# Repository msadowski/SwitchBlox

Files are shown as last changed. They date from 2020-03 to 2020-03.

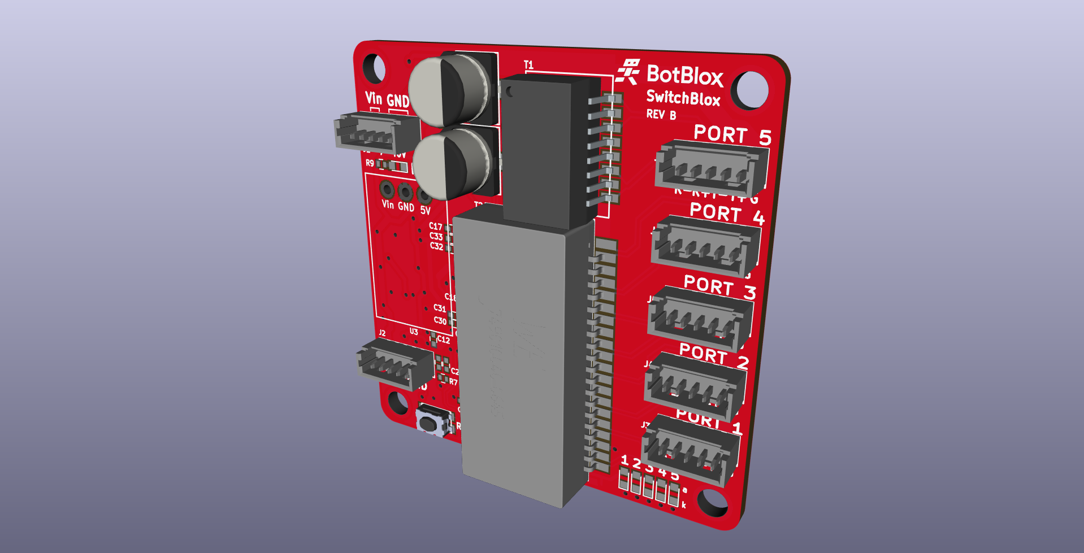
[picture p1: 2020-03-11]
Hardware/Reference Images/Iso.png

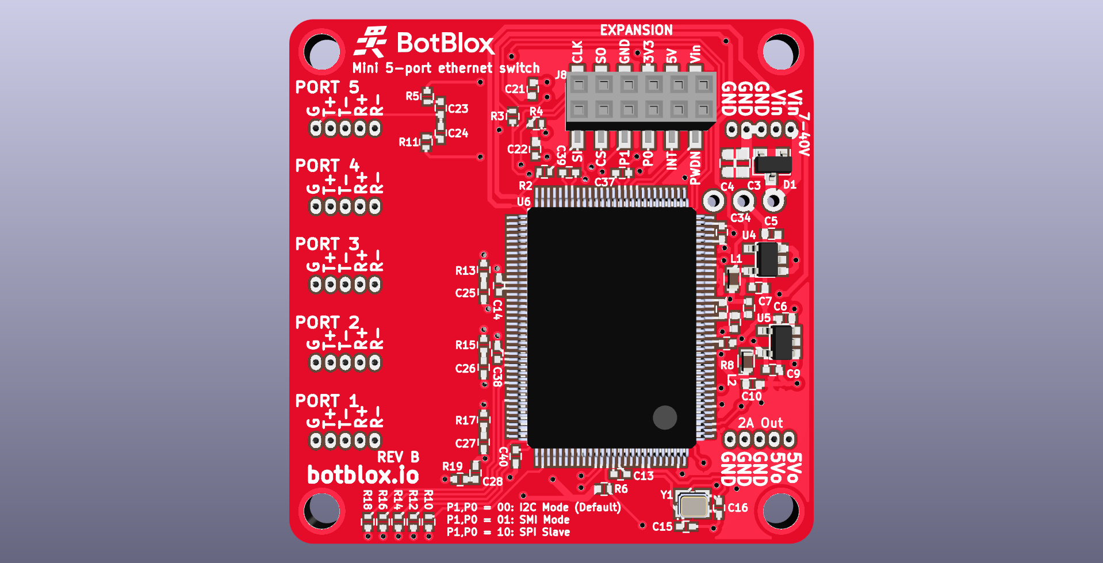
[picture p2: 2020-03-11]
Hardware/Reference Images/Bottom.png

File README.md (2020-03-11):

# SwitchBlox
Compact and robust 10/100MB 5 Port Ethernet Switch

Small Ethernet Switch for demanding applications.
Wide, protected input voltage range from 7 to 40V.
5V, 2A output available.
5 port ethernet network switch works out the box.
10/100MB Speed.
Auto MDI-X crossover.
All cables included, with extension cable set available.
SPI interface for advanced Rapid Spanning Tree (RSTP) applications.

In this repo you will find

- Hardware files (in Kicad)
- Firmware files (C++ mainly) (Haven't started this yet)
- Software files (Python) (Haven't started this yet, ideally I'd like a nice GUI to talk to the firmware to configure SwitchBlox)

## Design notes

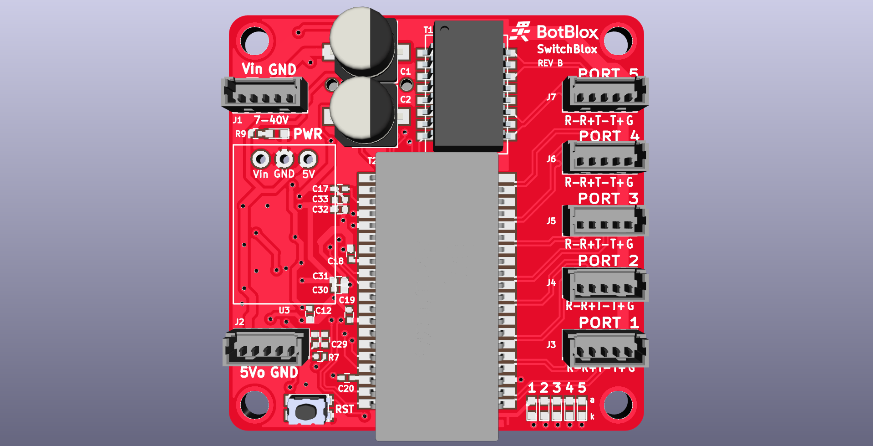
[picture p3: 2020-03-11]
Hardware/Reference Images/Front.png

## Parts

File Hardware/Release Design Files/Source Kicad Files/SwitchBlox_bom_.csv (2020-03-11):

Component | Description | Part | References | Value | Footprint | Quantity Per PCB | Datasheet | Voltage Rating | MPN | Tolerance | Field8 | Field4 | Field6 | Field5
1 | Unpolarized capacitor | C_Small | C3 C4 | 0.1u | C_0603 | 2 | ~ | 50V | CL10B104MB8NNNC
2 | Unpolarized capacitor | C_Small | C23 C24 C25 C26 C27 C28 | 1000p | C_0402 | 6 | ~ | 50V | GCM155R71H102KA37D
3 | Unpolarized capacitor | C_Small | C5 C6 C7 C8 C9 C10 C11 C12 C13 C14 C17 C18 C19 C20 C21 C22 C29 C30 C31 C32 C33 C34 C35 C36 C37 C38 C39 C40 | 1u | C_0402 | 28 | ~ | 10V | CL05A105MP5NNNC
4 | Unpolarized capacitor | C_Small | C15 C16 | 22p | C_0402 | 2 | ~ | 50V | CBR04C220F5GAC
5 | Polarised capacitor | CP1_Small | C1 C2 | 22u | Radial, Can - SMD | 2 | ~ | 50V | 865080643008
6 | Dual diode, common cathode | D_x2_KCom_AAK | D1 | 36Vb | SOT-23 | 1 | ~ |  | DESD34VS2SO-7
7 | LED generic | LED | D2 D3 D5 D7 D9 D11 | Green | LED_0603 | 6 | ~ |  | 150060GS75000
8 | Generic connector, single row, 01x06, script generated (kicad-library-utils/schlib/autogen/connector/) | Conn_01x06_Male | J8 | 2x3 | 2x3_2mm | 1 | ~
9 |  | CONN_HEADER_V_2 | J1 J2 | CONN_HEADER_V_2 | WM1731-ND | 2 |  |  | 0530470210
10 |  | CONN_HEADER_V_5 | J3 J4 J5 J6 J7 | CONN_HEADER_V_5 | WM1734-ND | 5 |  |  | 0530470510
11 | Ferrite bead, small symbol | Ferrite_Bead_Small | L1 L2 | Ferrite | R_0603 | 2 | ~ |  | MPZ1608S101ATAH0
12 | Net Tie, 2 pins | Net-Tie_2 | NT1 | Net-Tie_2 | NETTIE | 1 | ~ |  | DNI
13 | Resistor, small symbol | R_Small | R1 R2 R3 R4 R6 R7 | 10k | R_0402 | 6 | ~ |  | RR0510P-103-D
14 | Resistor, small symbol | R_Small | R8 | 12.4k | R_0402 | 1 | ~ |  | RR0510P-1242-D | 0.5%
15 | Resistor, small symbol | R_Small | R9 R10 R12 R14 R16 R18 | 220R | R_0402 | 6 | ~ |  | RR0510P-221-D
16 | Resistor, small symbol | R_Small | R5 R11 R13 R15 R17 R19 | 75R | R_0402 | 6 | ~ |  | ERJ-2RKF75R0X
17 | Push button switch, generic, two pins | SW_Push | SW1 | SW_Push | Tact, SMT | 1 |  |  | KMR621NG LFS
18 |  | H1102FNL | T1 | H1102FNL | H1102FNL | 1 |  |  | H1102FNL
19 |  | H1164NL | T2 | H1164NL | H1164NL | 1 |  |  | H1164NL
20 |  | DC-DC | U3 | DC-DC | OKI-78SR-5_1.5-W36HC | 1 |  |  | OKI-78SR-5/1.5-W36H-C
21 |  | KSZ8895MQXCA | U6 | KSZ8895MQXCA | PQFP-128 | 1 | 576-4855-ND |  | KSZ8895MQXCA |  | KSZ8895 Series 3.3 V 129 mA Integrated 5-Port 10/100 Managed Ethernet Switch | https://www.digikey.com/product-detail/en/microchip-technology/KSZ8895MQXCA/576-4855-ND/4901386 | Microchip | BFQFP-128 Microchip
22 |  | SOT-23-5 | U4 U5 | SOT-23-5 | SOT23-5 | 2 |  |  | MIC5504-3.3YM5-TR MIC5504- 1.2YM5-TR
23 | Two pin crystal | Crystal | Y1 | 25MHz | 2-SMD, No Lead | 1 | ~ |  | ECS-250-20-3X-TR
Component Groups: | 23
Component Count: | 85
Fitted Components: | 85
Number of PCBs: | 1
Total components: | 85
Schematic Version:
Schematic Date:
BoM Date: | 11/3/2018 00:00:17
Schematic Source: | D:\DawnSpark\_Upwork\SwitchBlox-master\Release Design Files\SwitchBlox.sch
KiCad Version: | Eeschema (5.0.0)

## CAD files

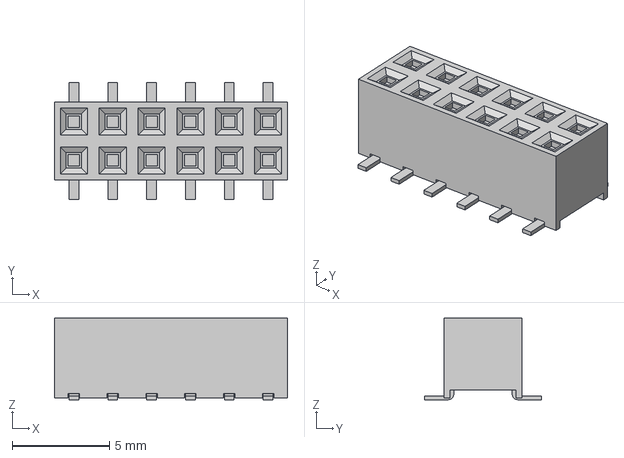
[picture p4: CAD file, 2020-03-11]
Hardware/Library Files/3D Models/A3-12DA-2SV.stp
12.0 x 6.00 x 4.20 mm

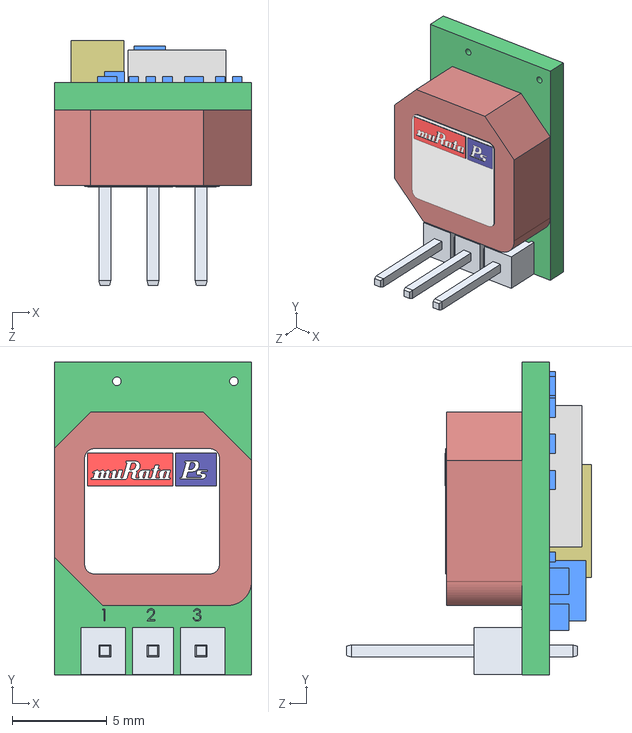
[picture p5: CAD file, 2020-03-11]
Hardware/Release Design Files/Source Kicad Files/3D/mps_dcdc_oki_78sr_horiz_a.step
10.4 x 16.5 x 12.9 mm

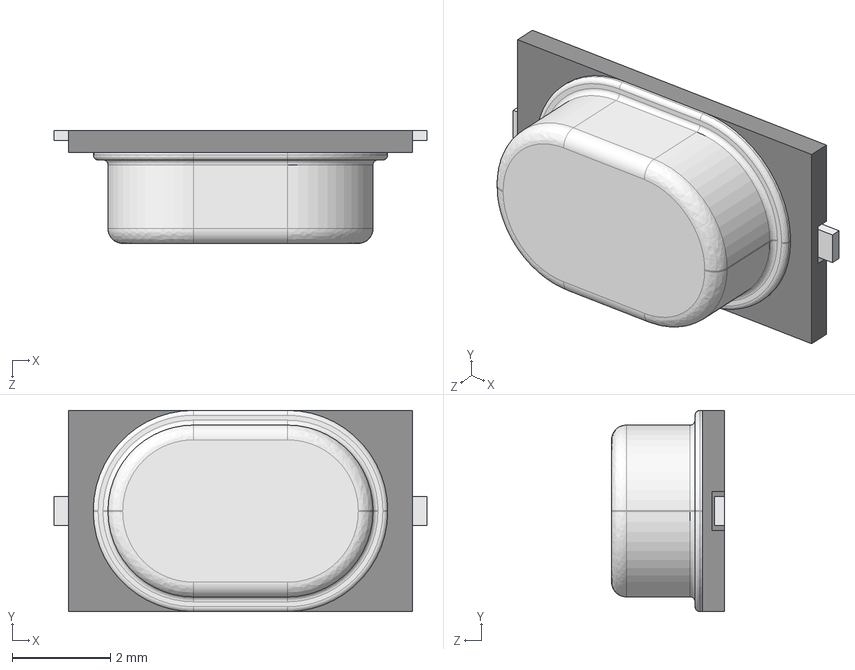
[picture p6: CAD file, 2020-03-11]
Hardware/Release Design Files/Source Kicad Files/3D/User Library-CSM-3X/User Library-CSM-3X.STEP
7.60 x 4.10 x 2.30 mm
User Library-CSM-3X_Fusion001
User Library-CSM-3X_Cut
User Library-CSM-3X_Fillet004

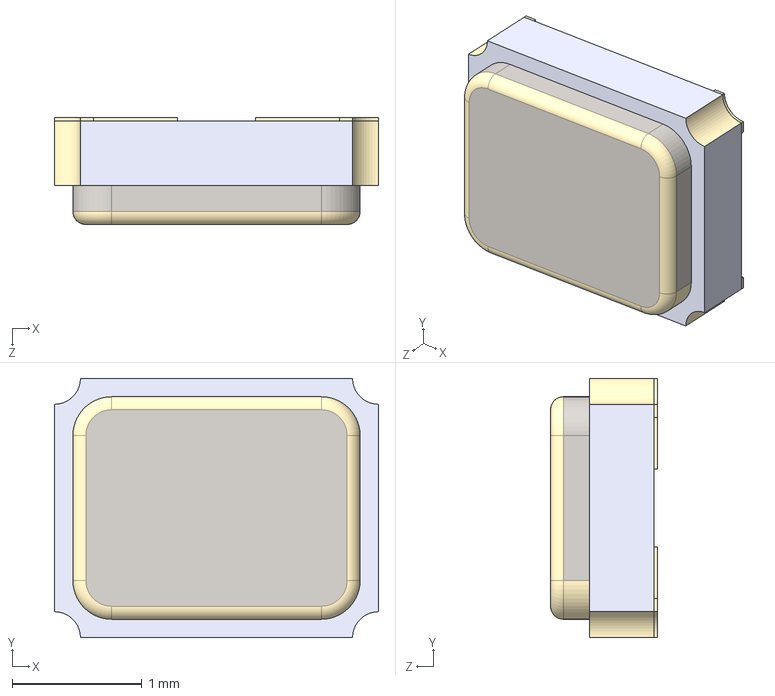
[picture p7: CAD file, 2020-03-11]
Hardware/Release Design Files/Source Kicad Files/3D/User Library-SM2520-4/User Library-SM2520-4.STEP
2.50 x 2.00 x 0.825 mm

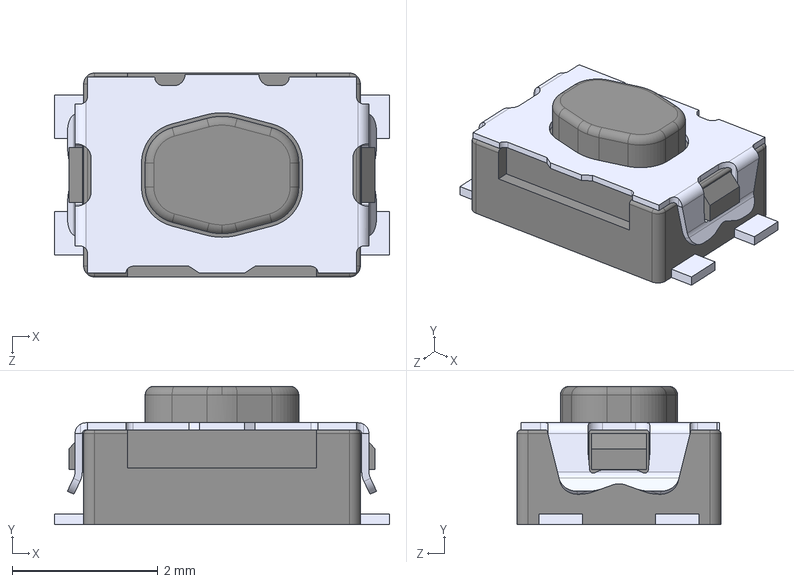
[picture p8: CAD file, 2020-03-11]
Hardware/Release Design Files/Source Kicad Files/3D/KMR621NG LFS--3DModel-STEP-56544.STEP
4.60 x 1.90 x 2.80 mm

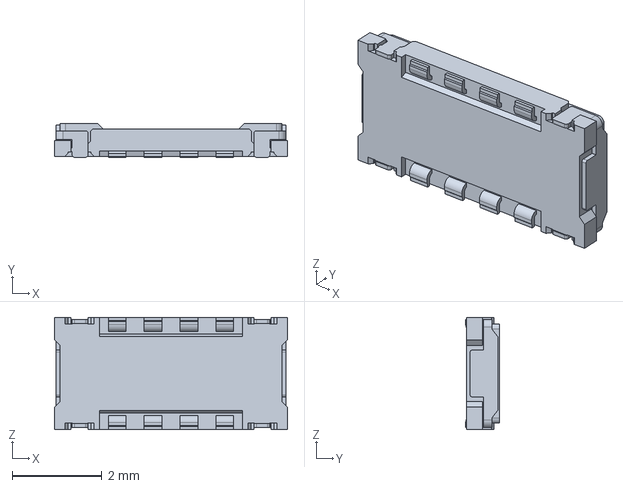
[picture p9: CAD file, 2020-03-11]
Hardware/Release Design Files/Source Kicad Files/3D/104249-0810_stp/1042490810.stp
5.20 x 0.75 x 2.50 mm

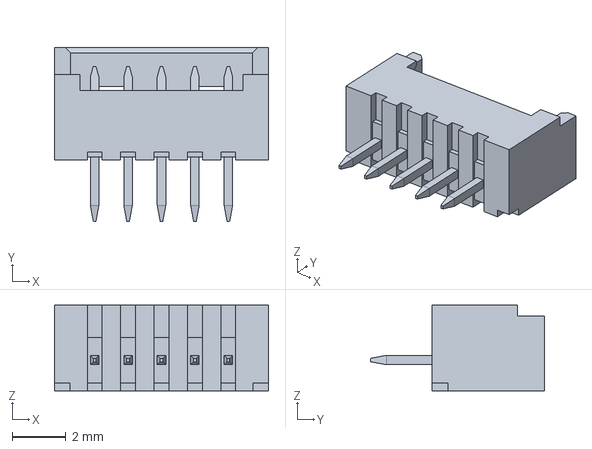
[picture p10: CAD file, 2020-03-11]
Hardware/Release Design Files/Source Kicad Files/3D/53047-0510_stp/530470510.stp
8.00 x 6.50 x 3.20 mm

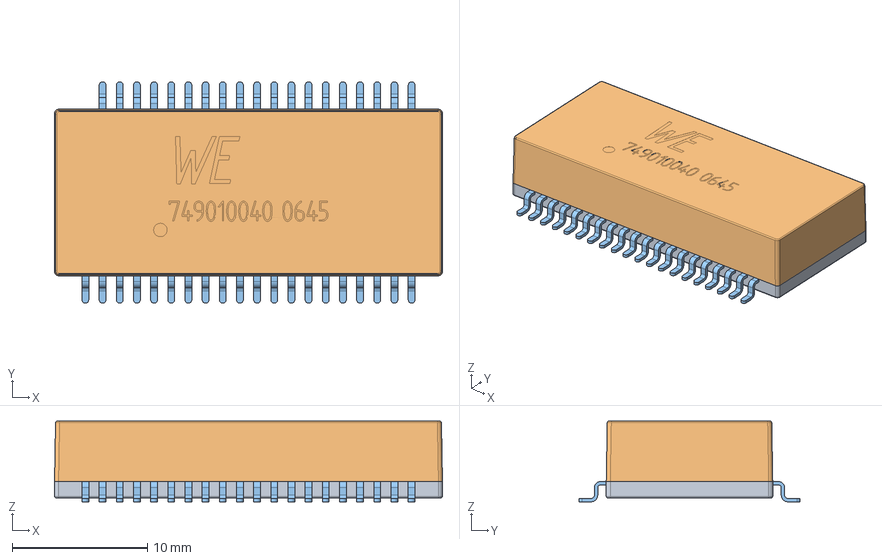
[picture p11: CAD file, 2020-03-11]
Hardware/Release Design Files/Source Kicad Files/3D/88347741-3-45803/45803.stp
28.7 x 16.4 x 5.97 mm

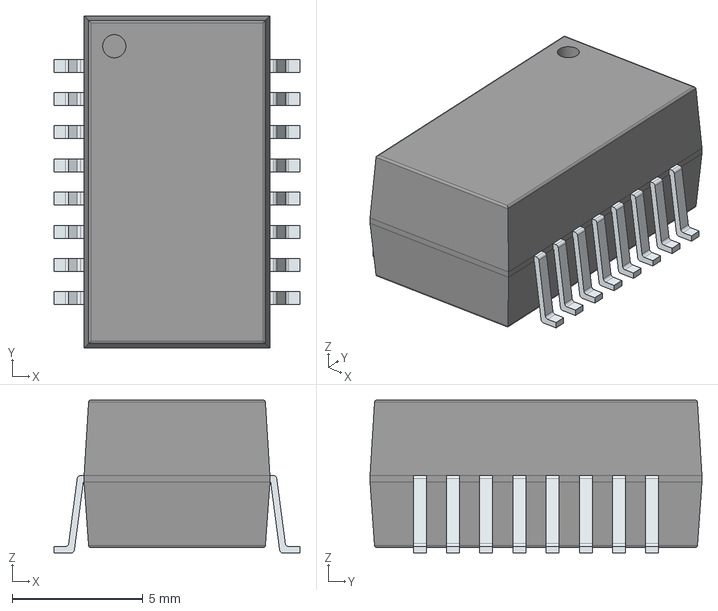
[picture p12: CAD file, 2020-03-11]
Hardware/Release Design Files/Source Kicad Files/3D/LIB_B78476A8065A003/B78476A8065A003/3D/B78476A8065A003.stp
9.40 x 12.7 x 5.85 mm
PinsArrayLR

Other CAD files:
Hardware/Library Files/3D Models/mps_dcdc_oki_78sr_horiz_a.step
Hardware/Release Design Files/Source Kicad Files/3D/LIB_B78476A8065A003/B78476A8065A003/3D/B78476A8065A003.stl
Hardware/Release Design Files/Source Kicad Files/3D/LIB_B78476A8065A003/B78476A8065A003/Allegro/soic127p940x585-16n.psm
Hardware/Release Design Files/Source Kicad Files/3D/LIB_B78476A8065A003/B78476A8065A003/DEHDL/B78476A8065A003/chips/chips.prt

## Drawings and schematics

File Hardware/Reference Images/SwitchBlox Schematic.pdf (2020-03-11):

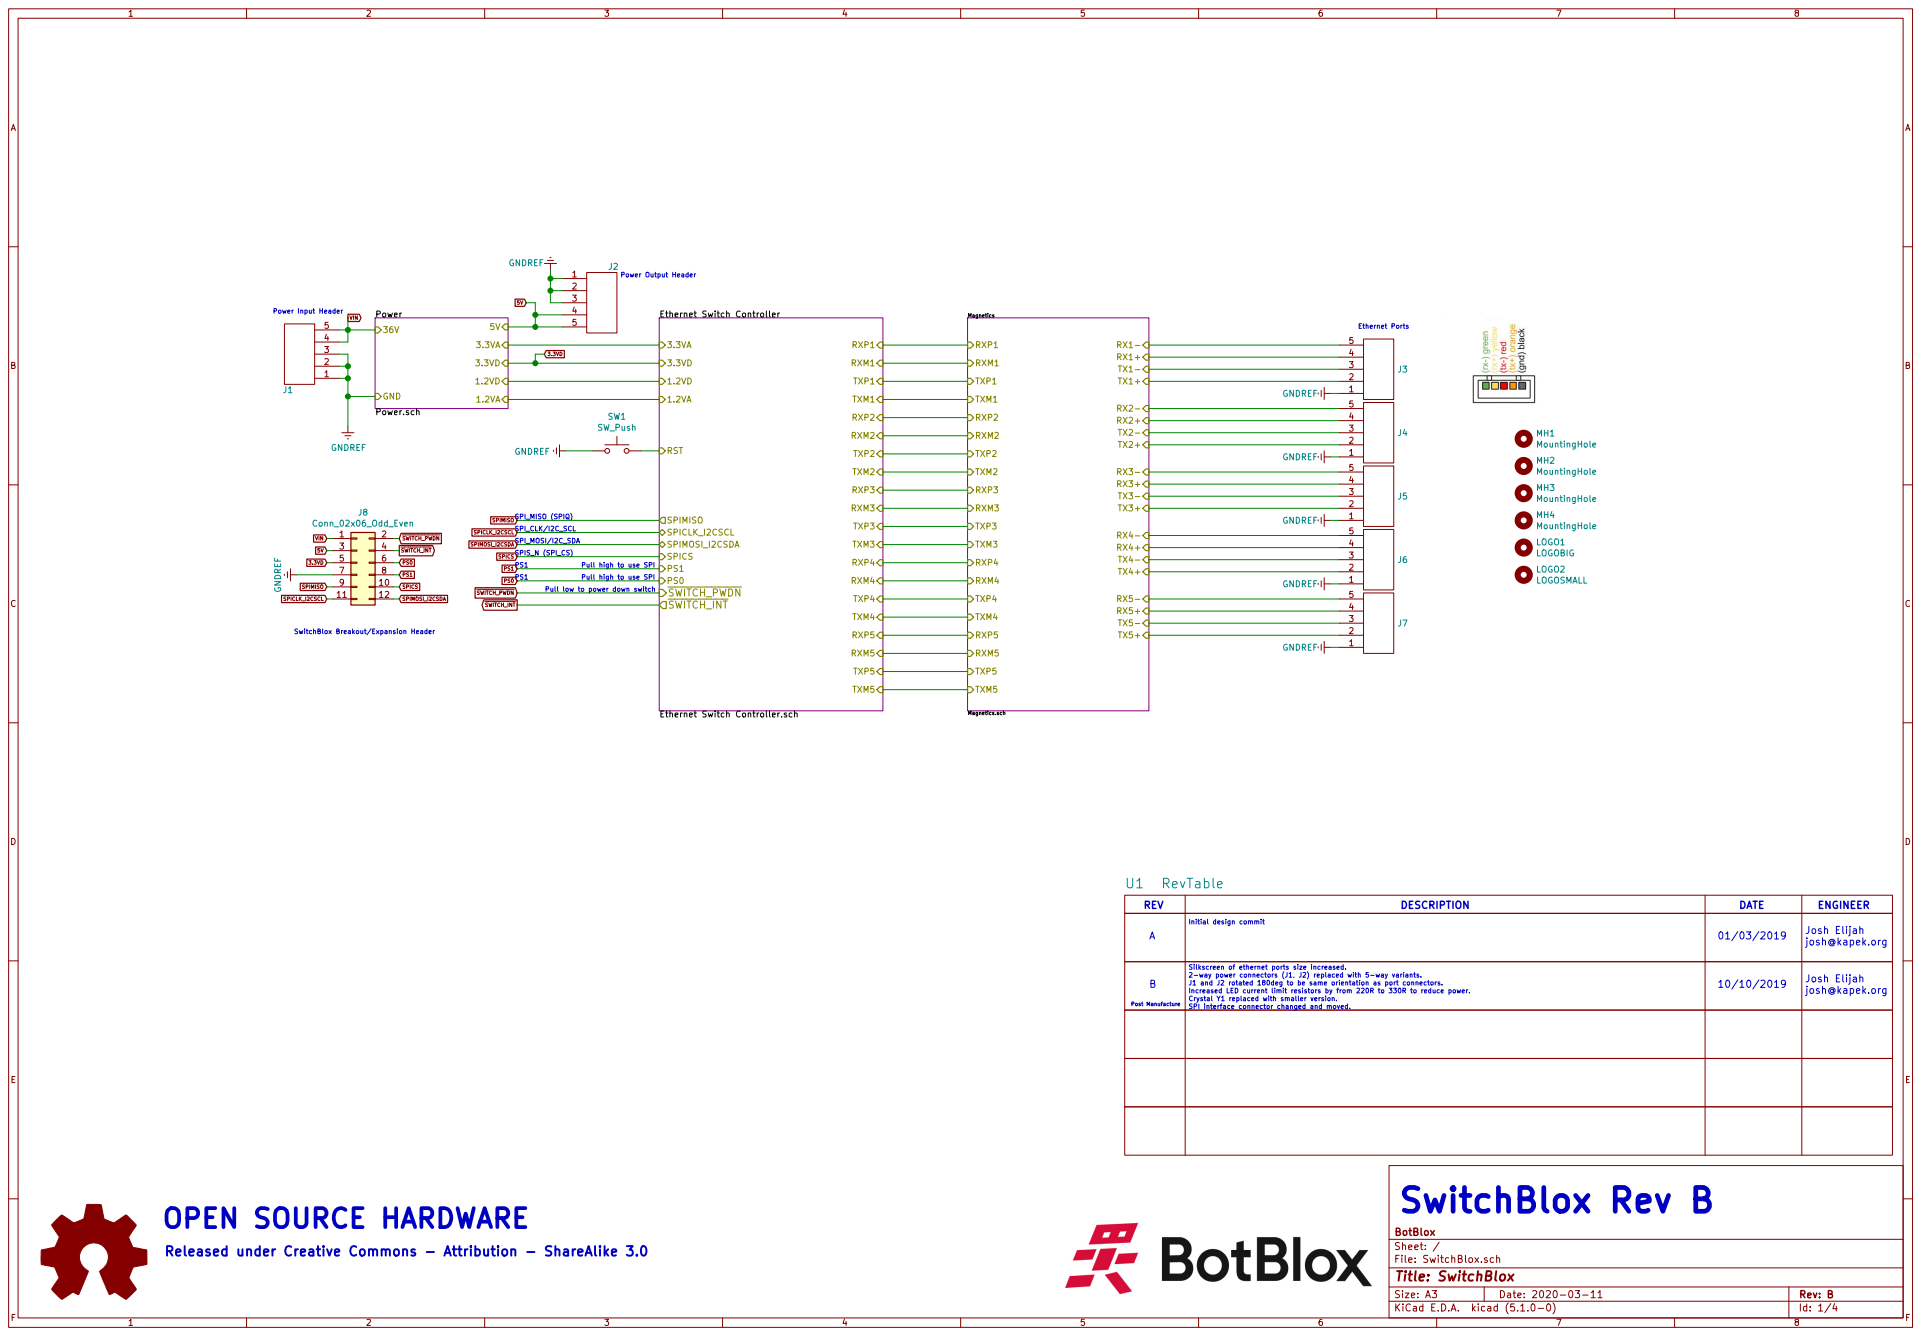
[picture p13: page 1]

SWITCH_INT VIN SwitchBlox Breakout/Expansion Header VIN1

Ethernet Switch Controller Ethernet Switch Controller.sch

A | | 01/03/2019 B | josh@kapek.org

Post Manufacture | Silkscreen of ethernet ports size increased. 2-way power connectors (J1, J2) replaced with 5-way variants. J1 and J2 rotated 180deg to be same orientation as port connectors. Increased LED current limit resistors by from 220R to 330R to reduce power. Crystal Y1 replaced with smaller version. SPI interface connector changed and moved. | | josh@kapek.org

10/10/2019 SwitchBlox Rev B OPEN SOURCE HARDWARE

File: SwitchBlox.sch Sheet: / BotBlox

Released under Creative Commons - Attribution - ShareAlike 3.0

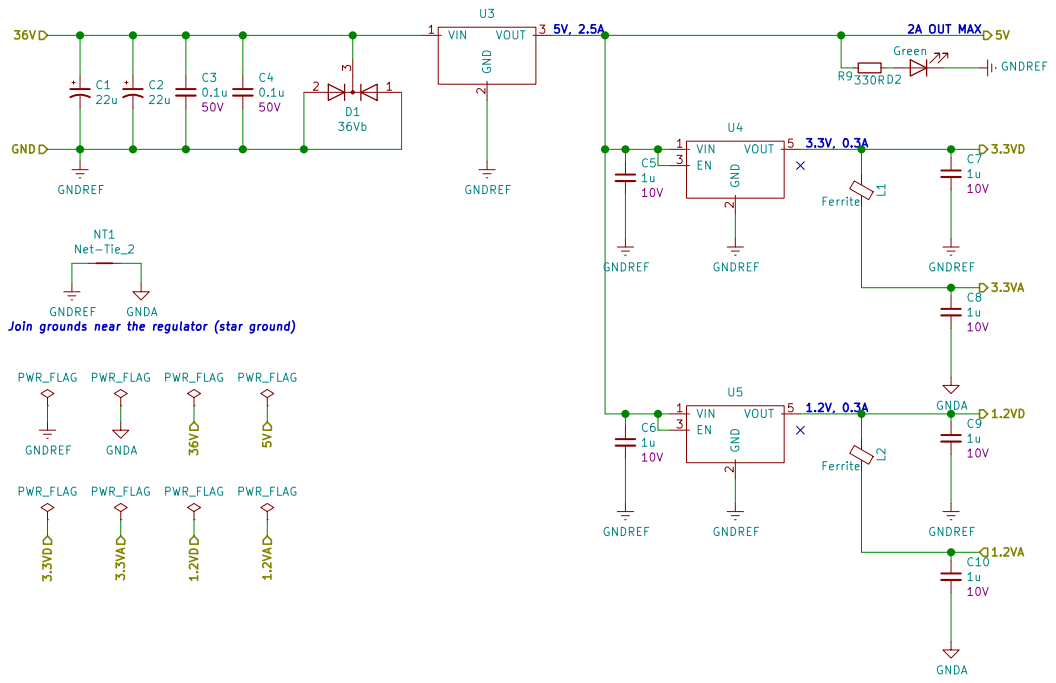
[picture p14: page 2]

File: Power.sch Sheet: /Power/ BotBlox

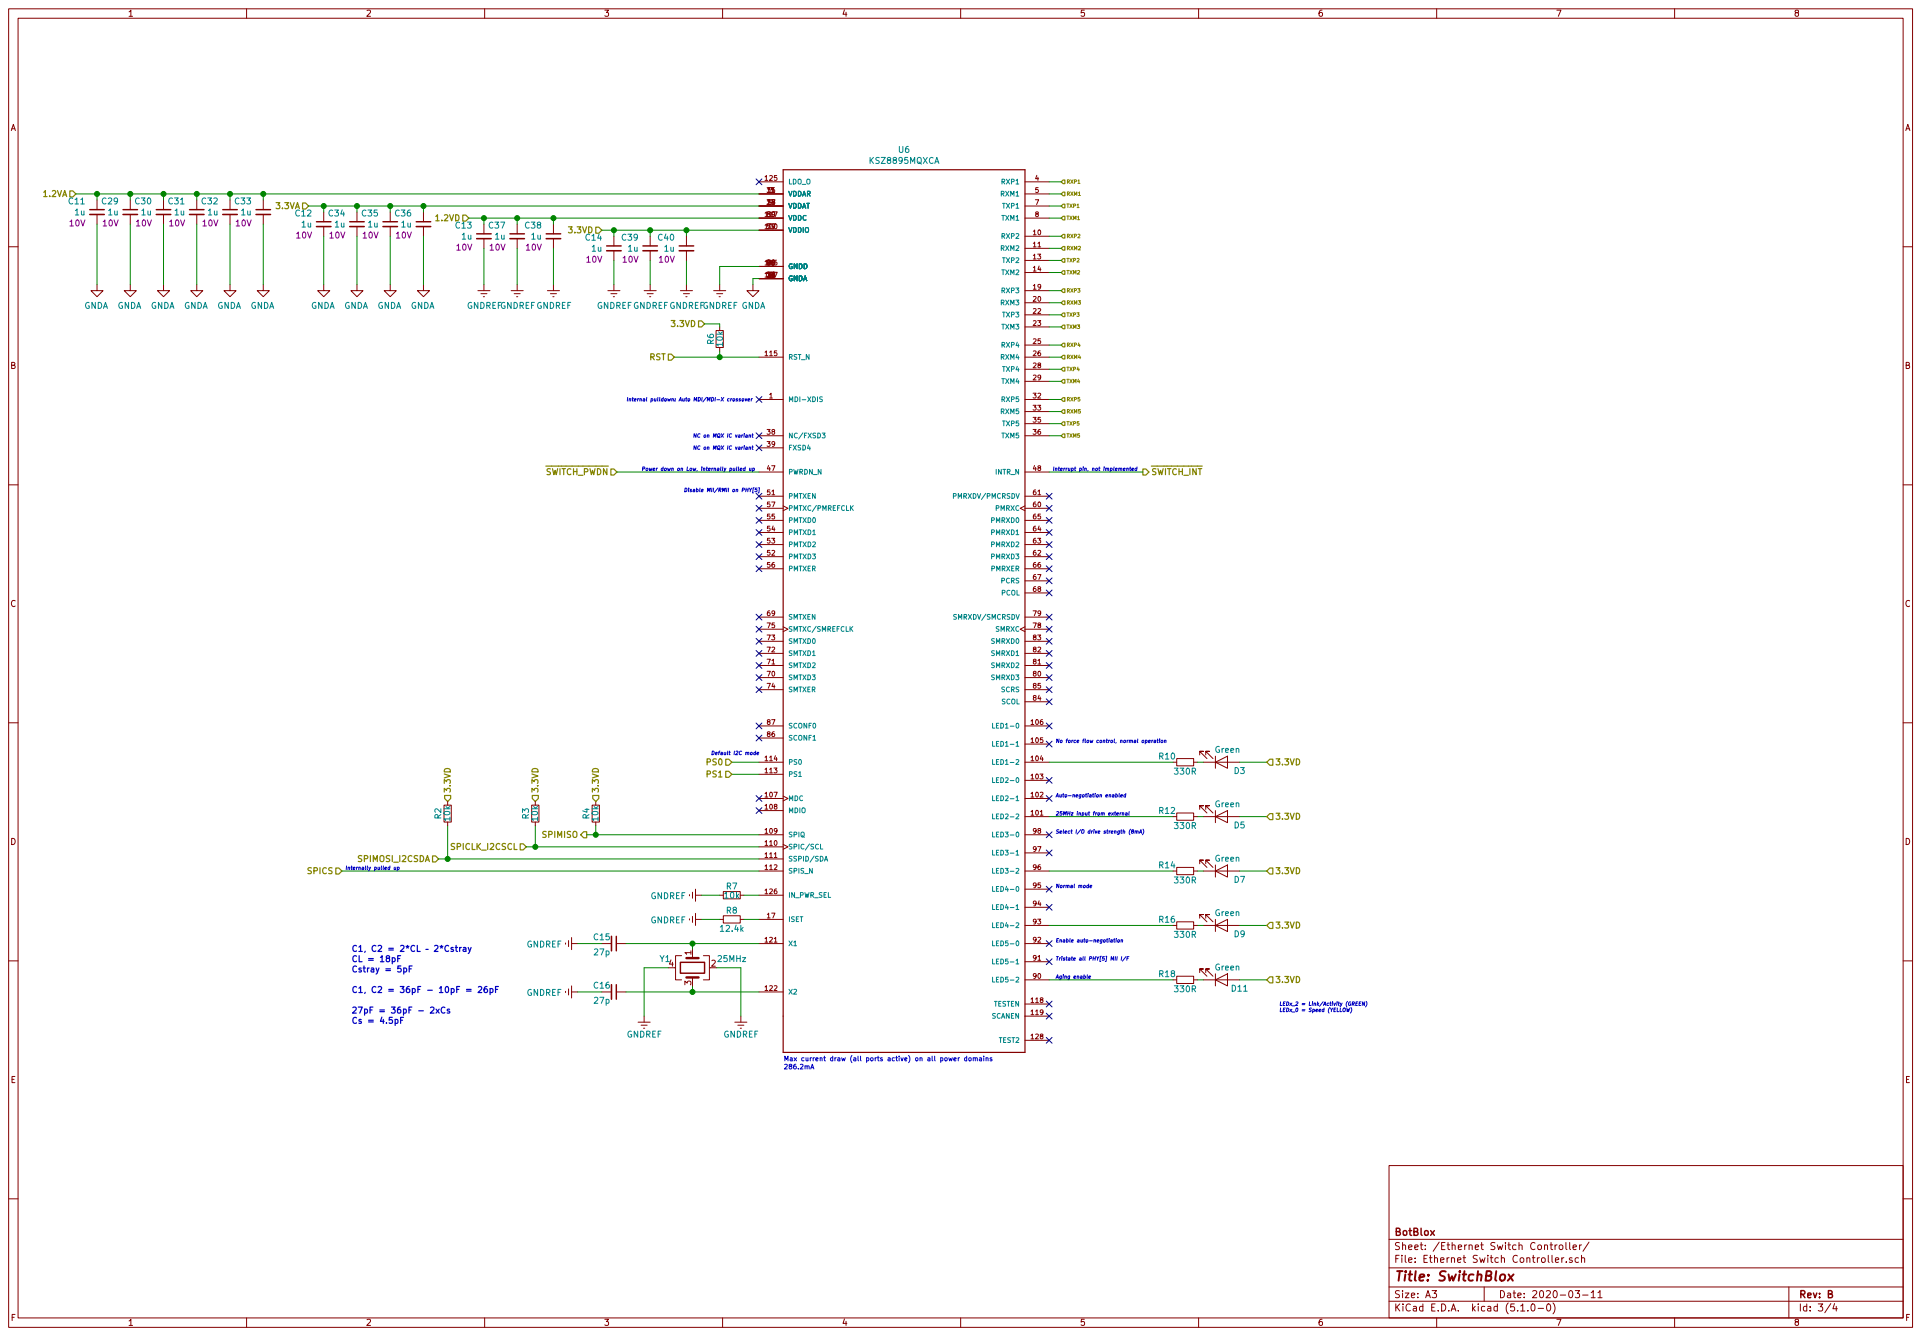
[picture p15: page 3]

Internal pulldown: Auto MDI/MDI-X crossover GNDA C11

No force flow control, normal operation Default I2C mode R6 10k 3.3VD

Disable MII/RMII on PHY[5]

LEDx_2 = Link/Activity (GREEN) LEDx_0 = Speed (YELLOW) D11 GreenD9 GreenD7 Green

Aging enable Tristate all PHY[5] MII I/F Enable auto-negotiation

Max current draw (all ports active) on all power domains

File: Ethernet Switch Controller.sch Sheet: /Ethernet Switch Controller/ BotBlox

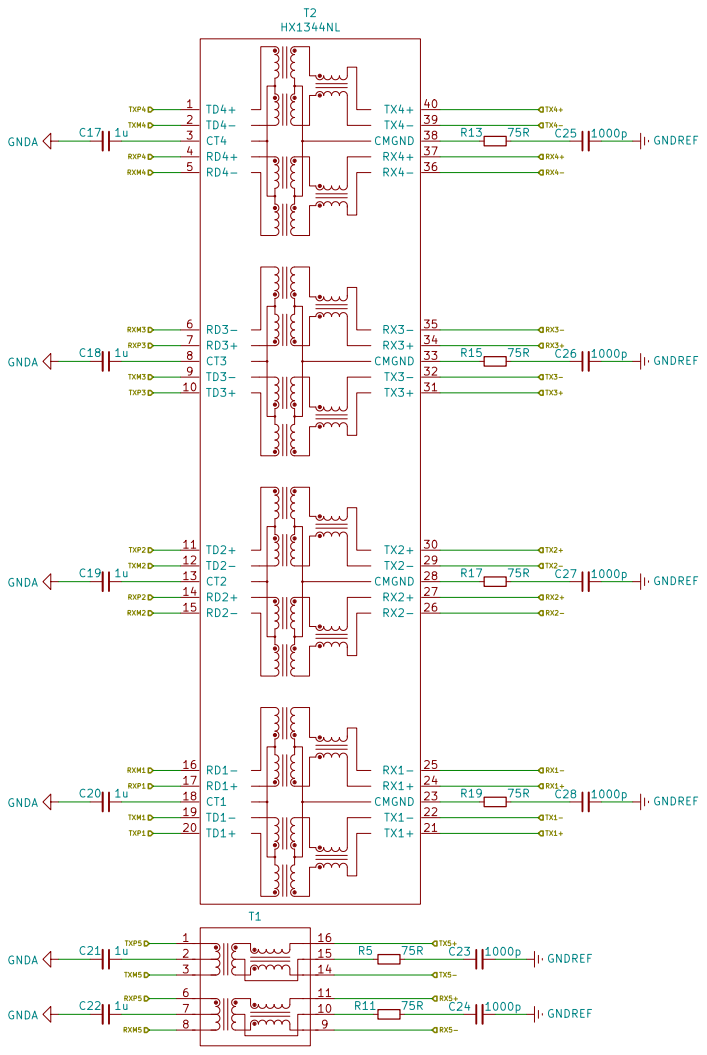
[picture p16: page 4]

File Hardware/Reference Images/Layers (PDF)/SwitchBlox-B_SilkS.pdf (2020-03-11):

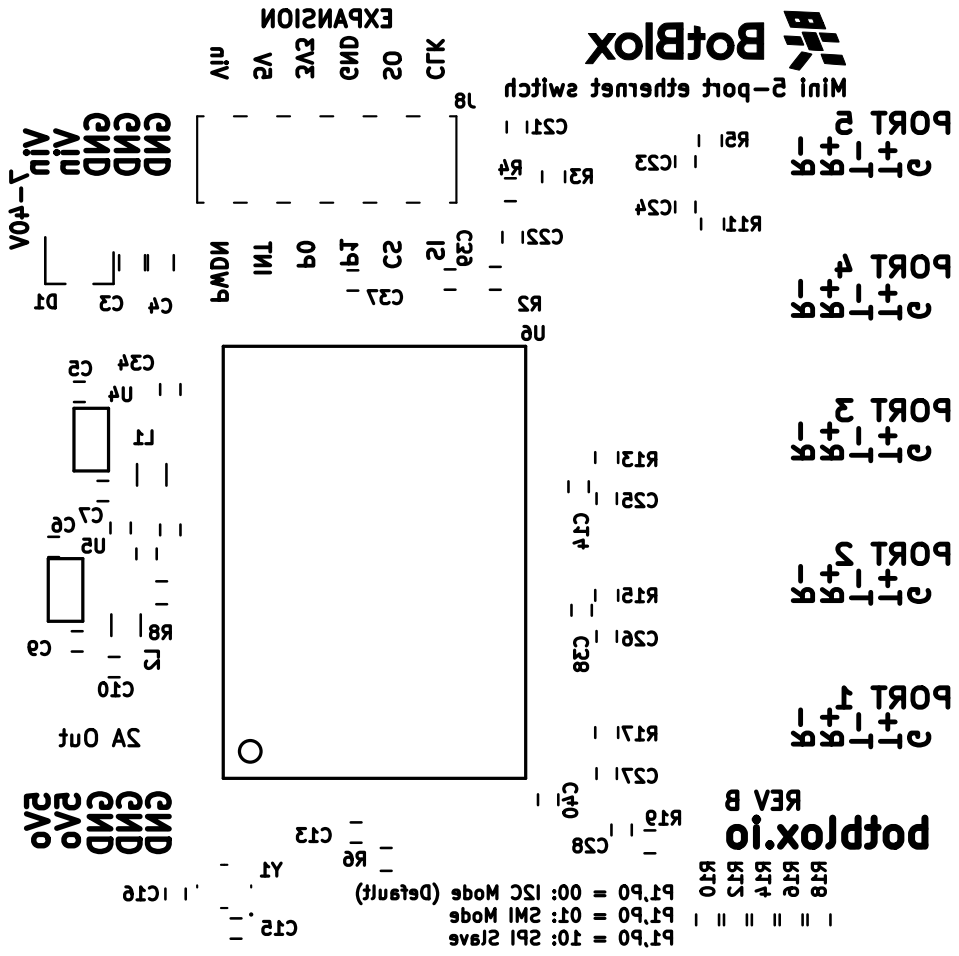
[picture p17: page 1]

EXPANSION 5Vo GND GND Vin botblox.io

P1,P0 = 00: I2C Mode (Default) P1,P0 = 01: SMI Mode P1,P0 = 10: SPI Slave SI INTP0P1 CS PWDN GND GND Vin 5V3V3 GND SOCLK

Mini 5-port ethernet switch REV B PORT 5 PORT 4 PORT 3 PORT 2 PORT 1 G G G G R- R+T- T+ R- R+T- T+ R- R+T- T+ R- R+T- T+

2A Out R- R+T- T+ G 5Vo GND 7-40V GND Vin

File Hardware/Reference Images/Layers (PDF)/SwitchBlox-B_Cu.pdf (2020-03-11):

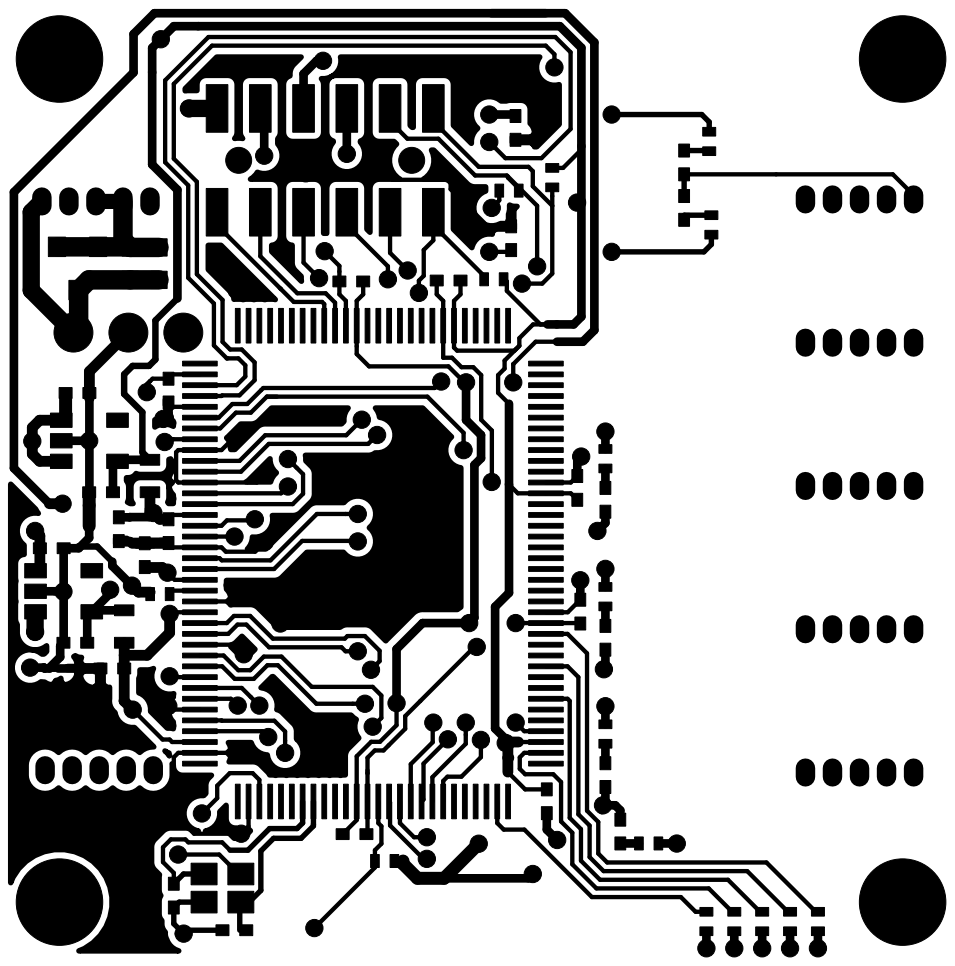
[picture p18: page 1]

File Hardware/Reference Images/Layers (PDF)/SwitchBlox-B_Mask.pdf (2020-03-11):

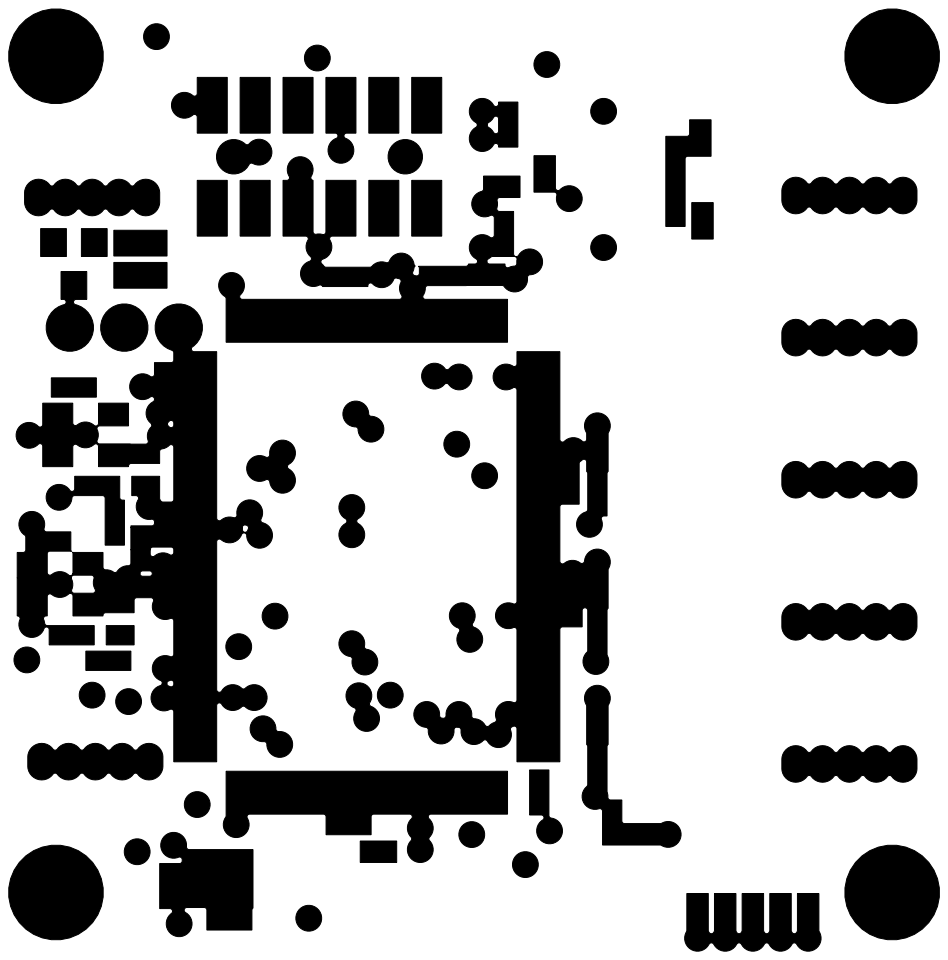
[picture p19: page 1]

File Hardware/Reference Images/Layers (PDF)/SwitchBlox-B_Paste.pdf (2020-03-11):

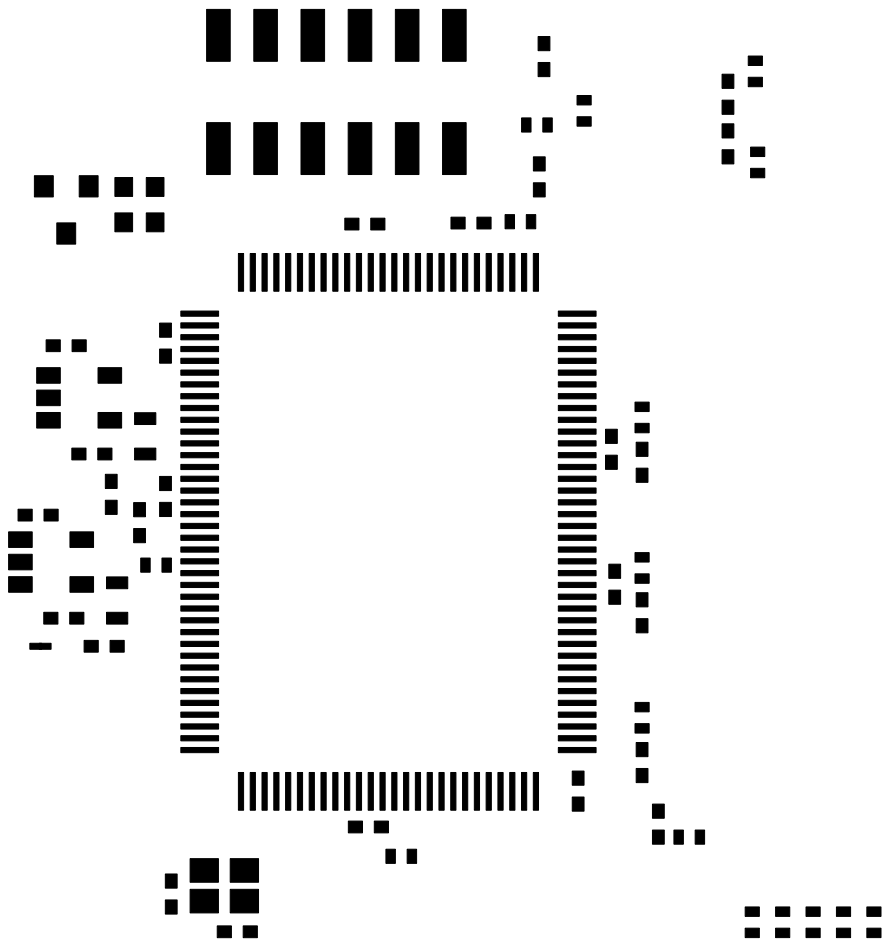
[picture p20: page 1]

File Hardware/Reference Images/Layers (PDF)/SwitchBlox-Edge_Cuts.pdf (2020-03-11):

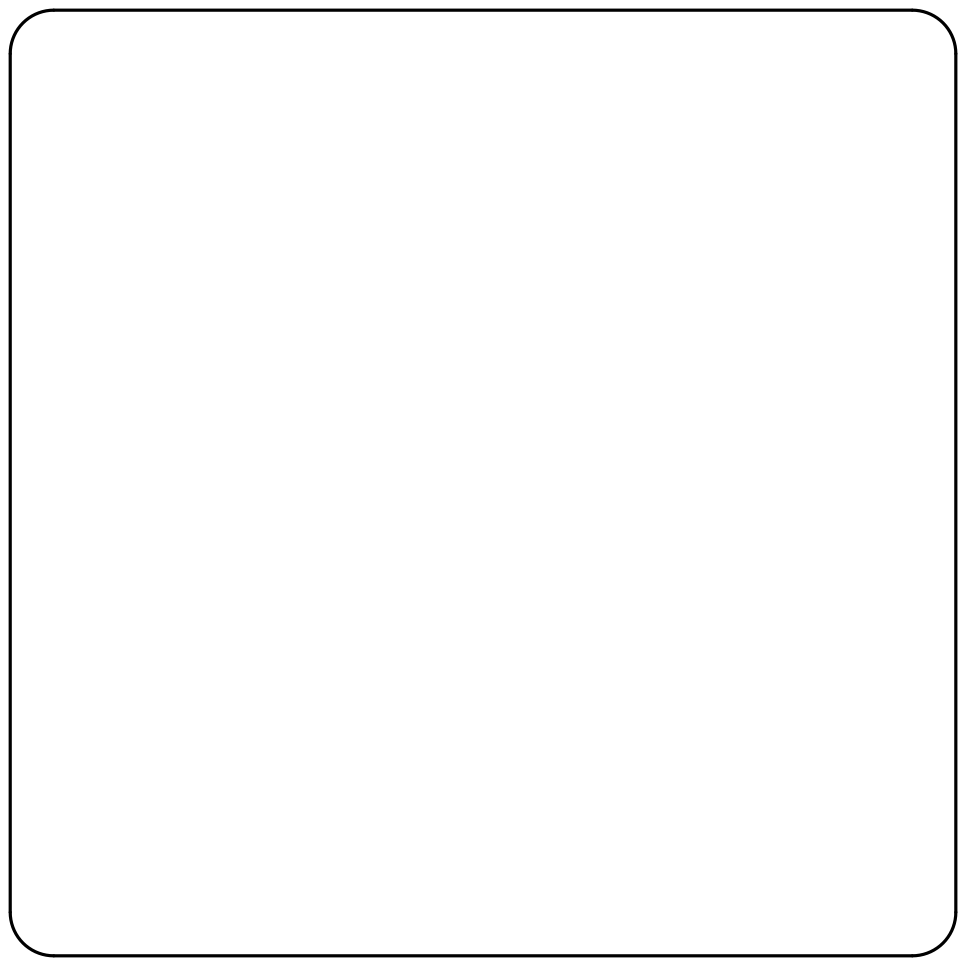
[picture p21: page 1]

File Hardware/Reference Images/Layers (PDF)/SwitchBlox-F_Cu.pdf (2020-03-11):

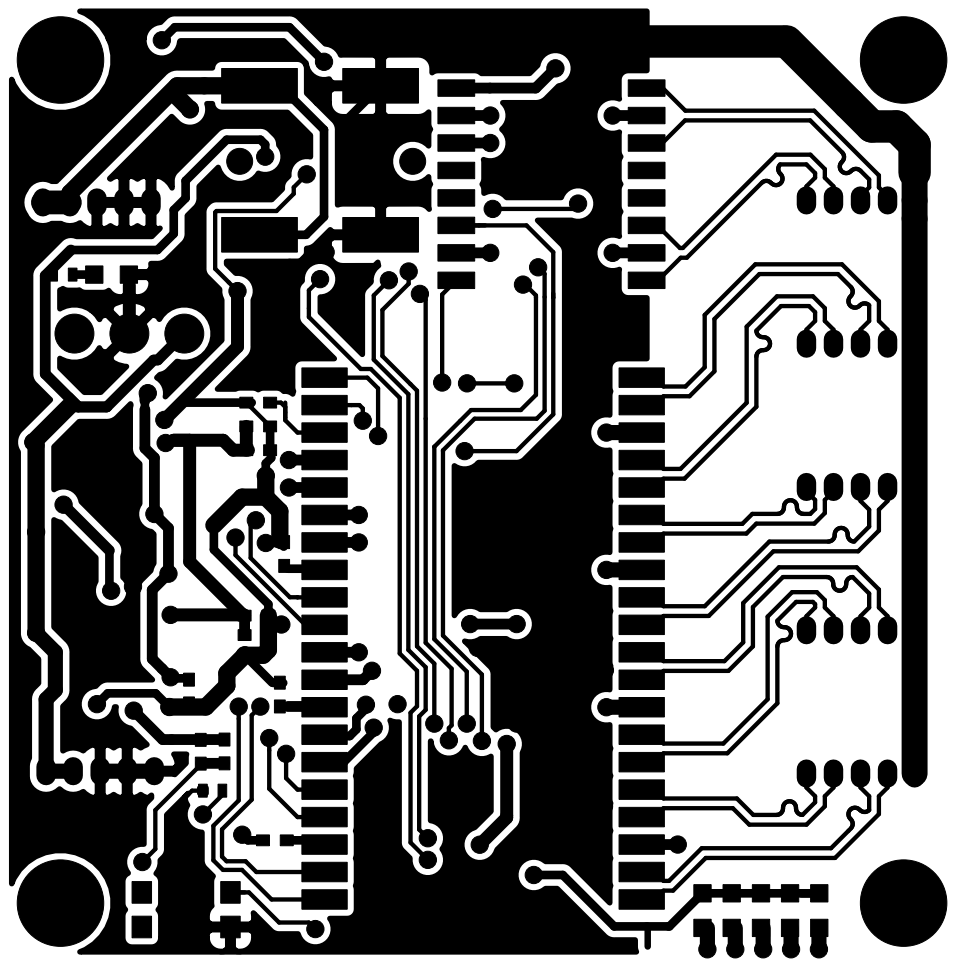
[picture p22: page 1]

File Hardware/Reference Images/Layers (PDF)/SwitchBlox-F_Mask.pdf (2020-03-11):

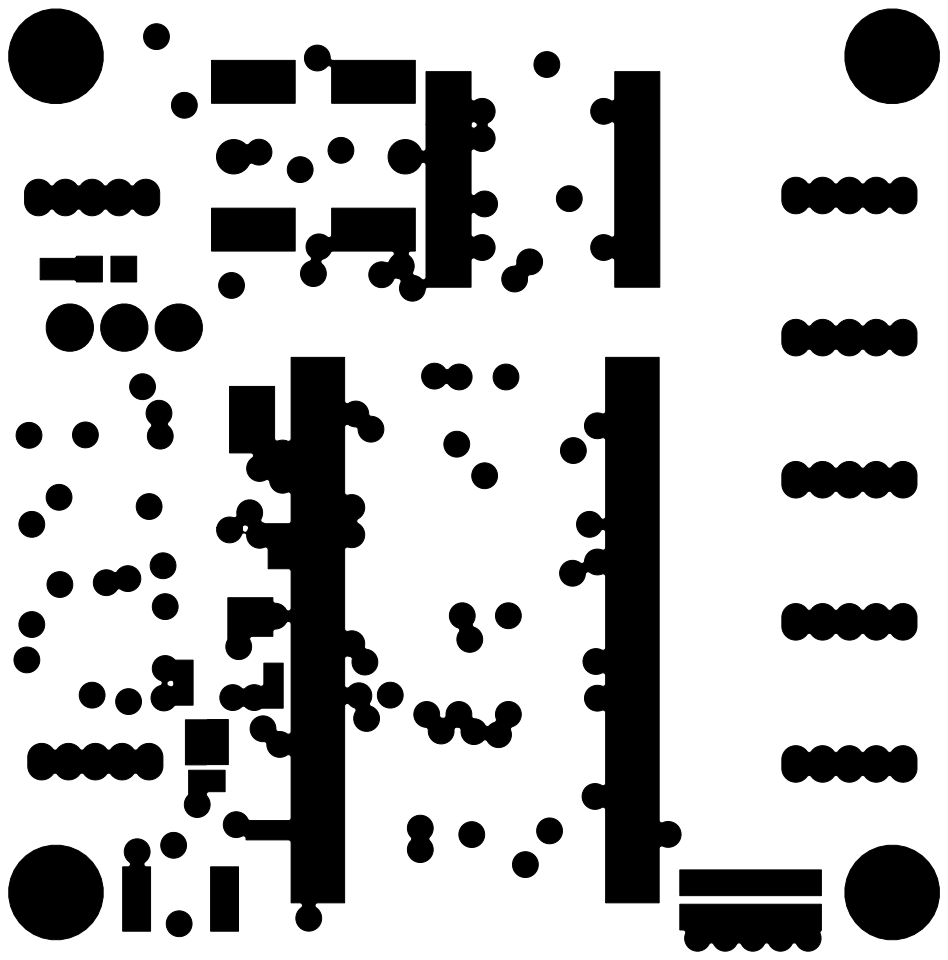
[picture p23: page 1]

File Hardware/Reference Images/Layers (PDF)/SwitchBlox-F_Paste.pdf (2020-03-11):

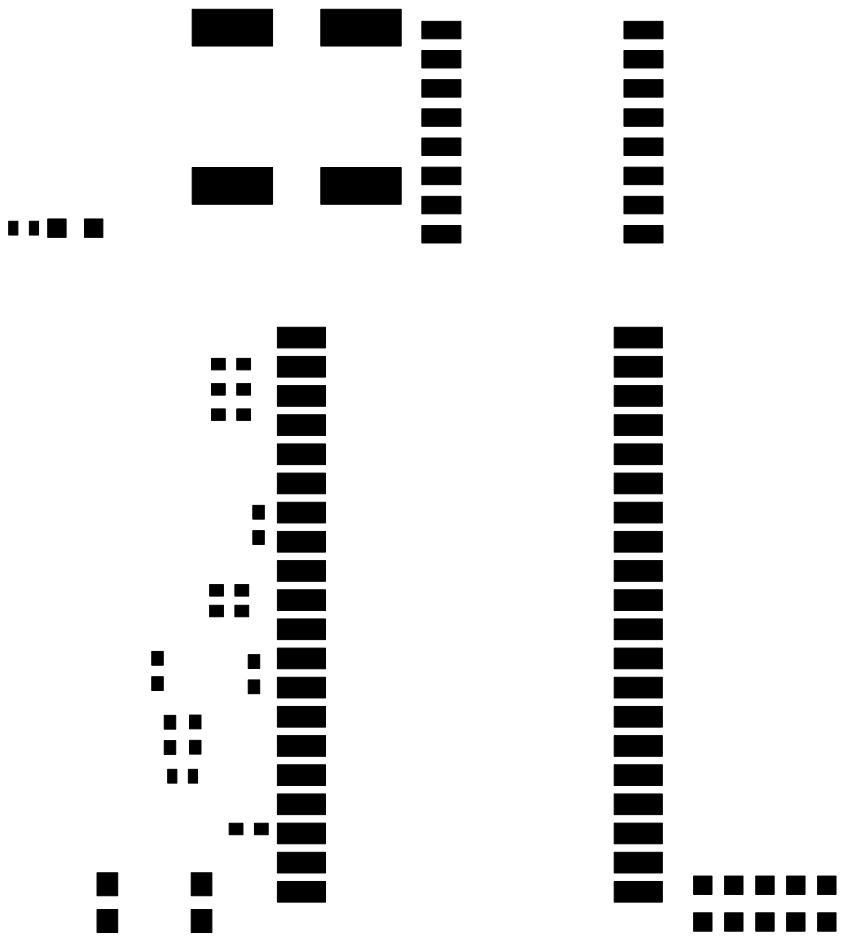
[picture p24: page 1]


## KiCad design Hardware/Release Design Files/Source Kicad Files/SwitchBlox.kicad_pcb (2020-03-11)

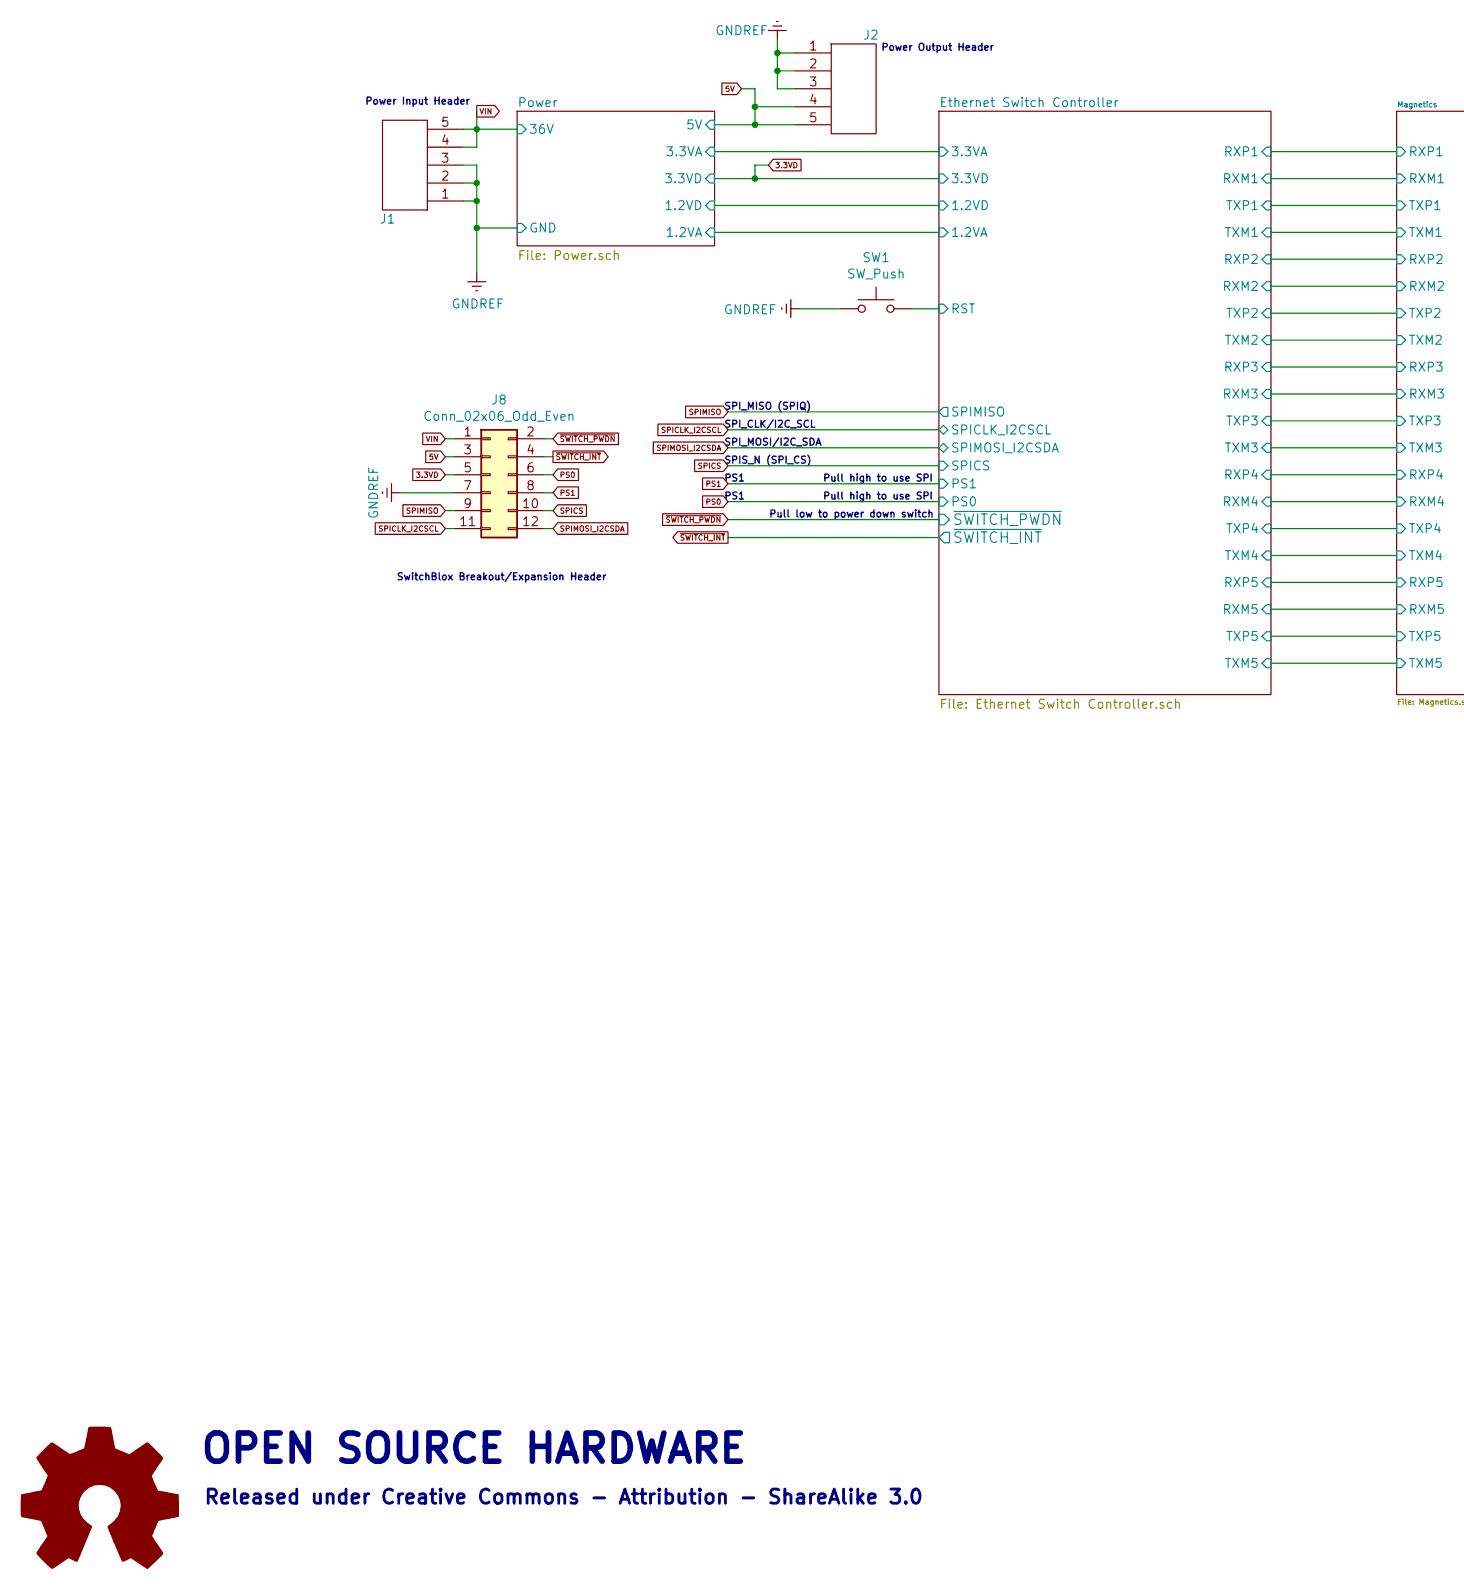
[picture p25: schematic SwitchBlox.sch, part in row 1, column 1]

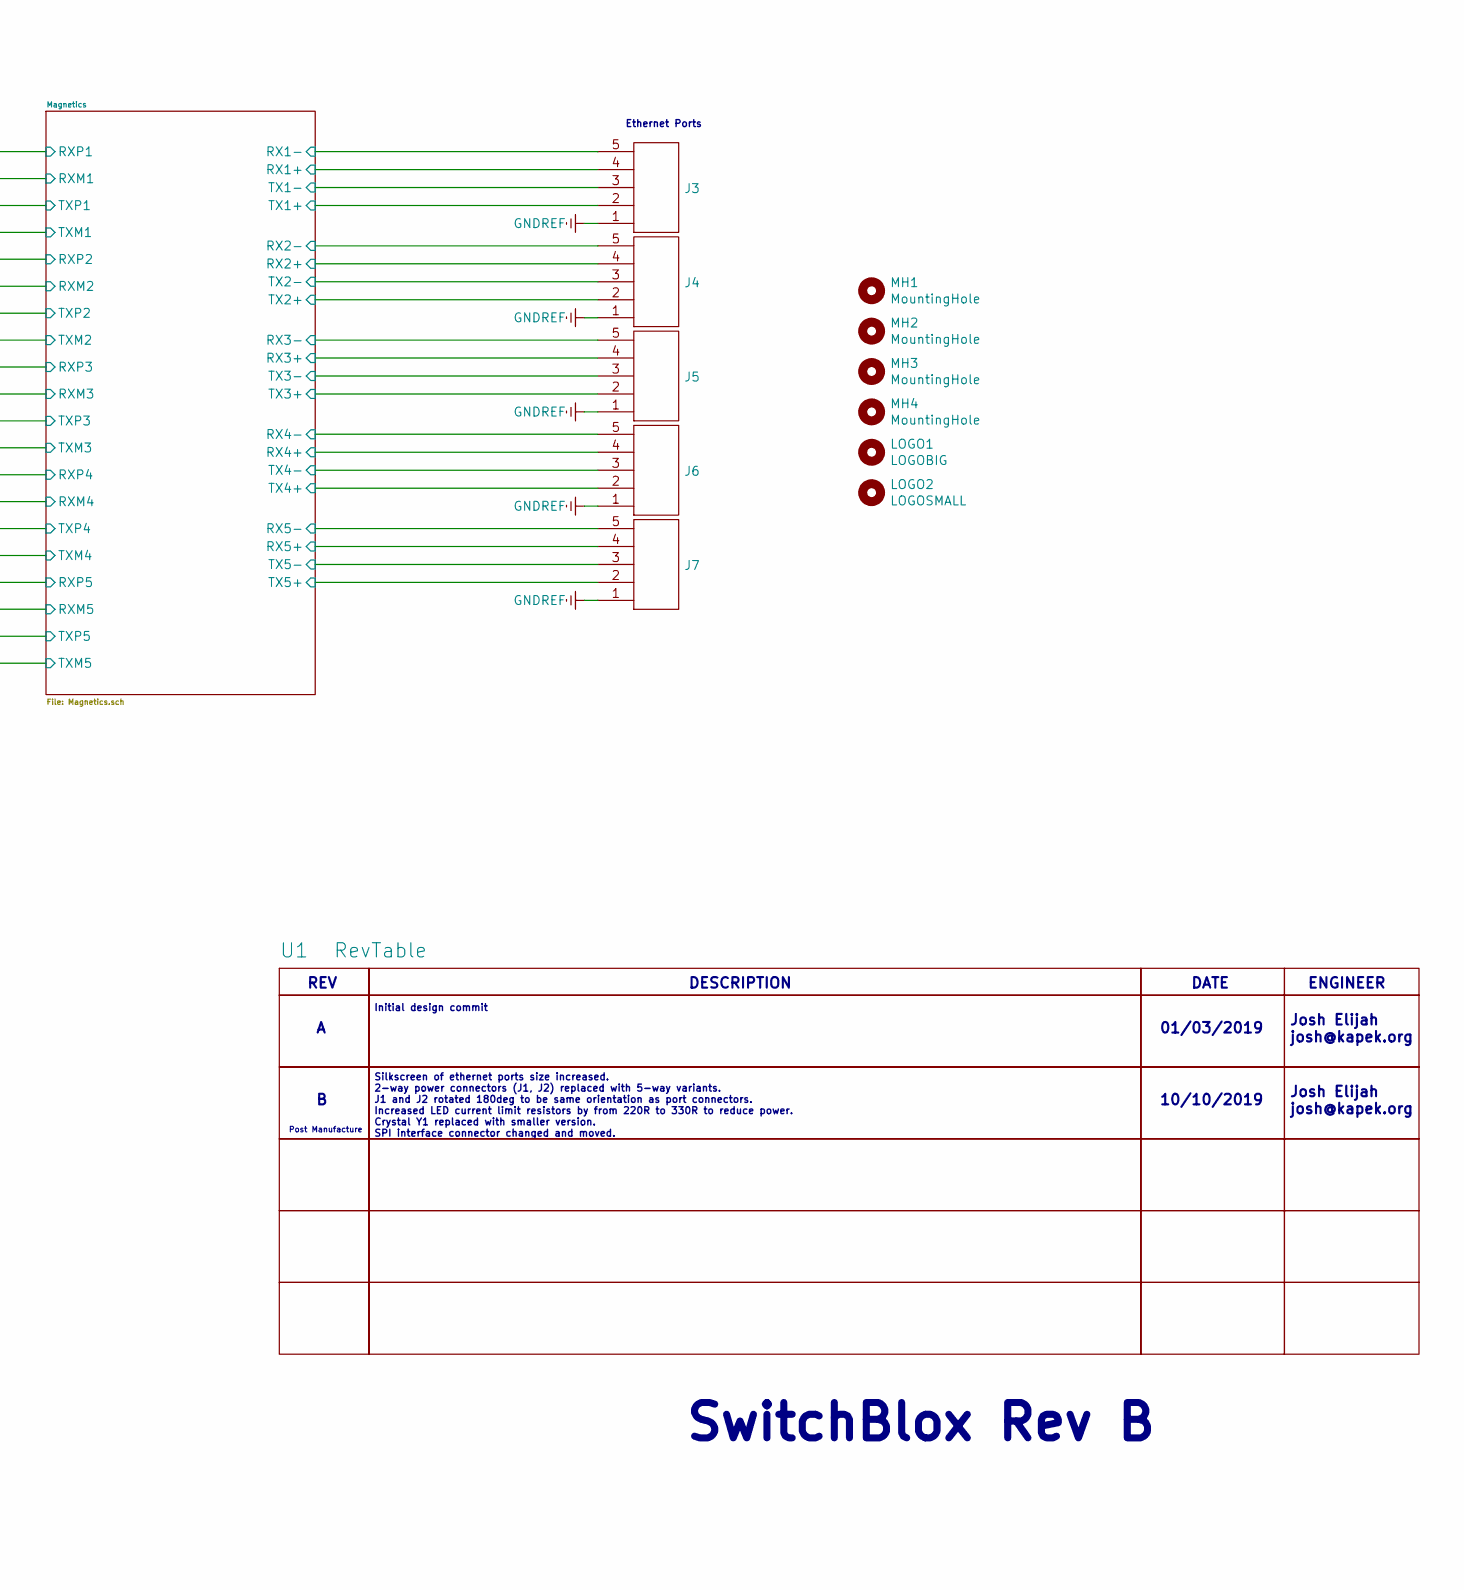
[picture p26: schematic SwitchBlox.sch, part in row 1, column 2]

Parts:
J1, J2, J3, J4, J5, J6, J7: CONN_HEADER_V_5; WM1734-ND; MPN 0530470510
J8: Conn_02x06_Odd_Even; A3-12DA-2SV(71); MPN A3-12DA-2SV(71)
LOGO1: LOGOBIG; LOGO4; MPN DNI
LOGO2: LOGOSMALL; LOGO2; MPN DNI
MH1, MH2, MH3, MH4: MountingHole; MountingHole_3mm; MPN DNI
SW1: SW_Push; Tact, SMT; MPN KMR621NG LFS
U1: RevTable

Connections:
3.3VD: J8.5; also elsewhere on the board
5V: J2.4, J2.5, J8.3; also elsewhere on the board
/Ethernet Switch Controller/RST: SW1.2; also elsewhere on the board
/Magnetics/RX1+: J3.4; also elsewhere on the board
/Magnetics/RX1-: J3.5; also elsewhere on the board
/Magnetics/RX2+: J4.4; also elsewhere on the board
/Magnetics/RX2-: J4.5; also elsewhere on the board
/Magnetics/RX3+: J5.4; also elsewhere on the board
/Magnetics/RX3-: J5.5; also elsewhere on the board
/Magnetics/RX4+: J6.4; also elsewhere on the board
/Magnetics/RX4-: J6.5; also elsewhere on the board
/Magnetics/RX5+: J7.4; also elsewhere on the board
/Magnetics/RX5-: J7.5; also elsewhere on the board
/Magnetics/TX1+: J3.2; also elsewhere on the board
/Magnetics/TX1-: J3.3; also elsewhere on the board
/Magnetics/TX2+: J4.2; also elsewhere on the board
/Magnetics/TX2-: J4.3; also elsewhere on the board
/Magnetics/TX3+: J5.2; also elsewhere on the board
/Magnetics/TX3-: J5.3; also elsewhere on the board
/Magnetics/TX4+: J6.2; also elsewhere on the board
/Magnetics/TX4-: J6.3; also elsewhere on the board
/Magnetics/TX5+: J7.2; also elsewhere on the board
/Magnetics/TX5-: J7.3; also elsewhere on the board
GNDREF: J1.1, J1.2, J1.3, J2.1, J2.2, J2.3, J3.1, J4.1, J5.1, J6.1, J7.1, J8.7, SW1.1; also elsewhere on the board
PS0: J8.6; also elsewhere on the board
PS1: J8.8; also elsewhere on the board
SPICLK_I2CSCL: J8.11; also elsewhere on the board
SPICS: J8.10; also elsewhere on the board
SPIMISO: J8.9; also elsewhere on the board
SPIMOSI_I2CSDA: J8.12; also elsewhere on the board
VIN: J1.4, J1.5, J8.1; also elsewhere on the board
~SWITCH_INT: J8.4; also elsewhere on the board
~SWITCH_PWDN: J8.2; also elsewhere on the board

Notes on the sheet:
SPIS_N (SPI_CS)
SPI_MISO (SPIQ)
SPI_CLK/I2C_SCL
SPI_MOSI/I2C_SDA
PS1
Pull high to use SPI
REV
DESCRIPTION
DATE
ENGINEER
Initial design commit
Josh Elijah josh@kapek.org
01/03/2019
Post Manufacture
Silkscreen of ethernet ports size increased. 2-way power connectors (J1, J2) replaced with 5-way variants. J1 and J2 rotated 180deg to be same orientation as port connectors. Increased LED current limit resistors by from 220R to 330R to reduce power. Crystal Y1 replaced with smaller version. SPI in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
Pull low to power down switch
SwitchBlox Breakout/Expansion Header
Power Input Header
Power Output Header
Ethernet Ports
10/10/2019
SwitchBlox Rev B
OPEN SOURCE HARDWARE
Released under Creative Commons - Attribution - ShareAlike 3.0

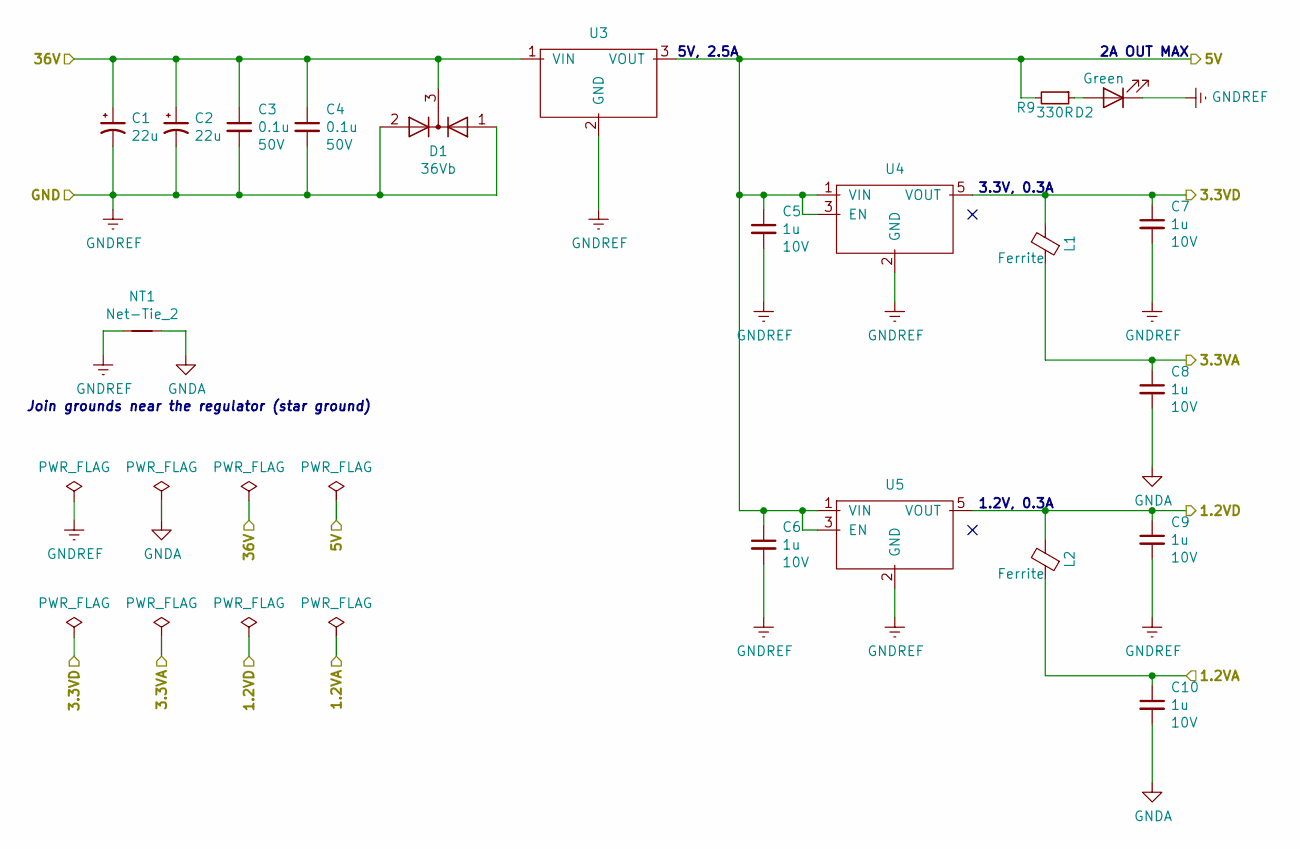
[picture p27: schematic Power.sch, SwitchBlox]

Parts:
C1, C2: 22u; Radial, Can - SMD; Voltage Rating 50V; MPN 865080643008
C3, C4: 0.1u; C_0603; Voltage Rating 50V; MPN CL10B104KB8NNNC
C5, C6, C7, C8, C9, C10: 1u; C_0402; Voltage Rating 10V; MPN CL05A105MP5NNNC
D1: 36Vb; SOT-23; MPN DESD34VS2SO-7
D2: Green; LED_0603; MPN 150060GS75000
L1, L2: Ferrite; R_0603; MPN MPZ1608S101ATAH0
NT1: Net-Tie_2; NETTIE; MPN DNI
R9: 330R; R_0402; MPN CRGCQ0402F330R
U3: DC-DC; OKI-78SR-5_1.5-W36HC; MPN OKI-78SR-5/1.5-W36H-C
U4: SOT-23-5; SOT23-5; MPN MIC5504-3.3YM5-TR
U5: SOT-23-5; SOT23-5; MPN MIC5504-1.2YM5-TR

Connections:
3.3VD: C7.1, L1.2, U4.5 (VOUT); also elsewhere on the board
5V: C5.1, C6.1, R9.2, U3.3 (VOUT), U4.1 (VIN), U4.3 (EN), U5.1 (VIN), U5.3 (EN); also elsewhere on the board
/Ethernet Switch Controller/1.2VA: C10.1, L2.1; also elsewhere on the board
/Ethernet Switch Controller/1.2VD: C9.1, L2.2, U5.5 (VOUT); also elsewhere on the board
/Ethernet Switch Controller/3.3VA: C8.1, L1.1; also elsewhere on the board
GNDA: C8.2, C10.2, NT1.2; also elsewhere on the board
GNDREF: C1.2, C2.2, C3.2, C4.2, C5.2, C6.2, C7.2, C9.2, D1.1 (A), D1.2 (A), D2.1 (K), NT1.1, U3.2 (GND), U4.2 (GND), U5.2 (GND); also elsewhere on the board
unnamed: D2.2 (A), R9.1
VIN: C1.1, C2.1, C3.1, C4.1, D1.3 (K), U3.1 (VIN); also elsewhere on the board

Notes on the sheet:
5V, 2.5A
3.3V, 0.3A
1.2V, 0.3A
2A OUT MAX
Join grounds near the regulator (star ground)

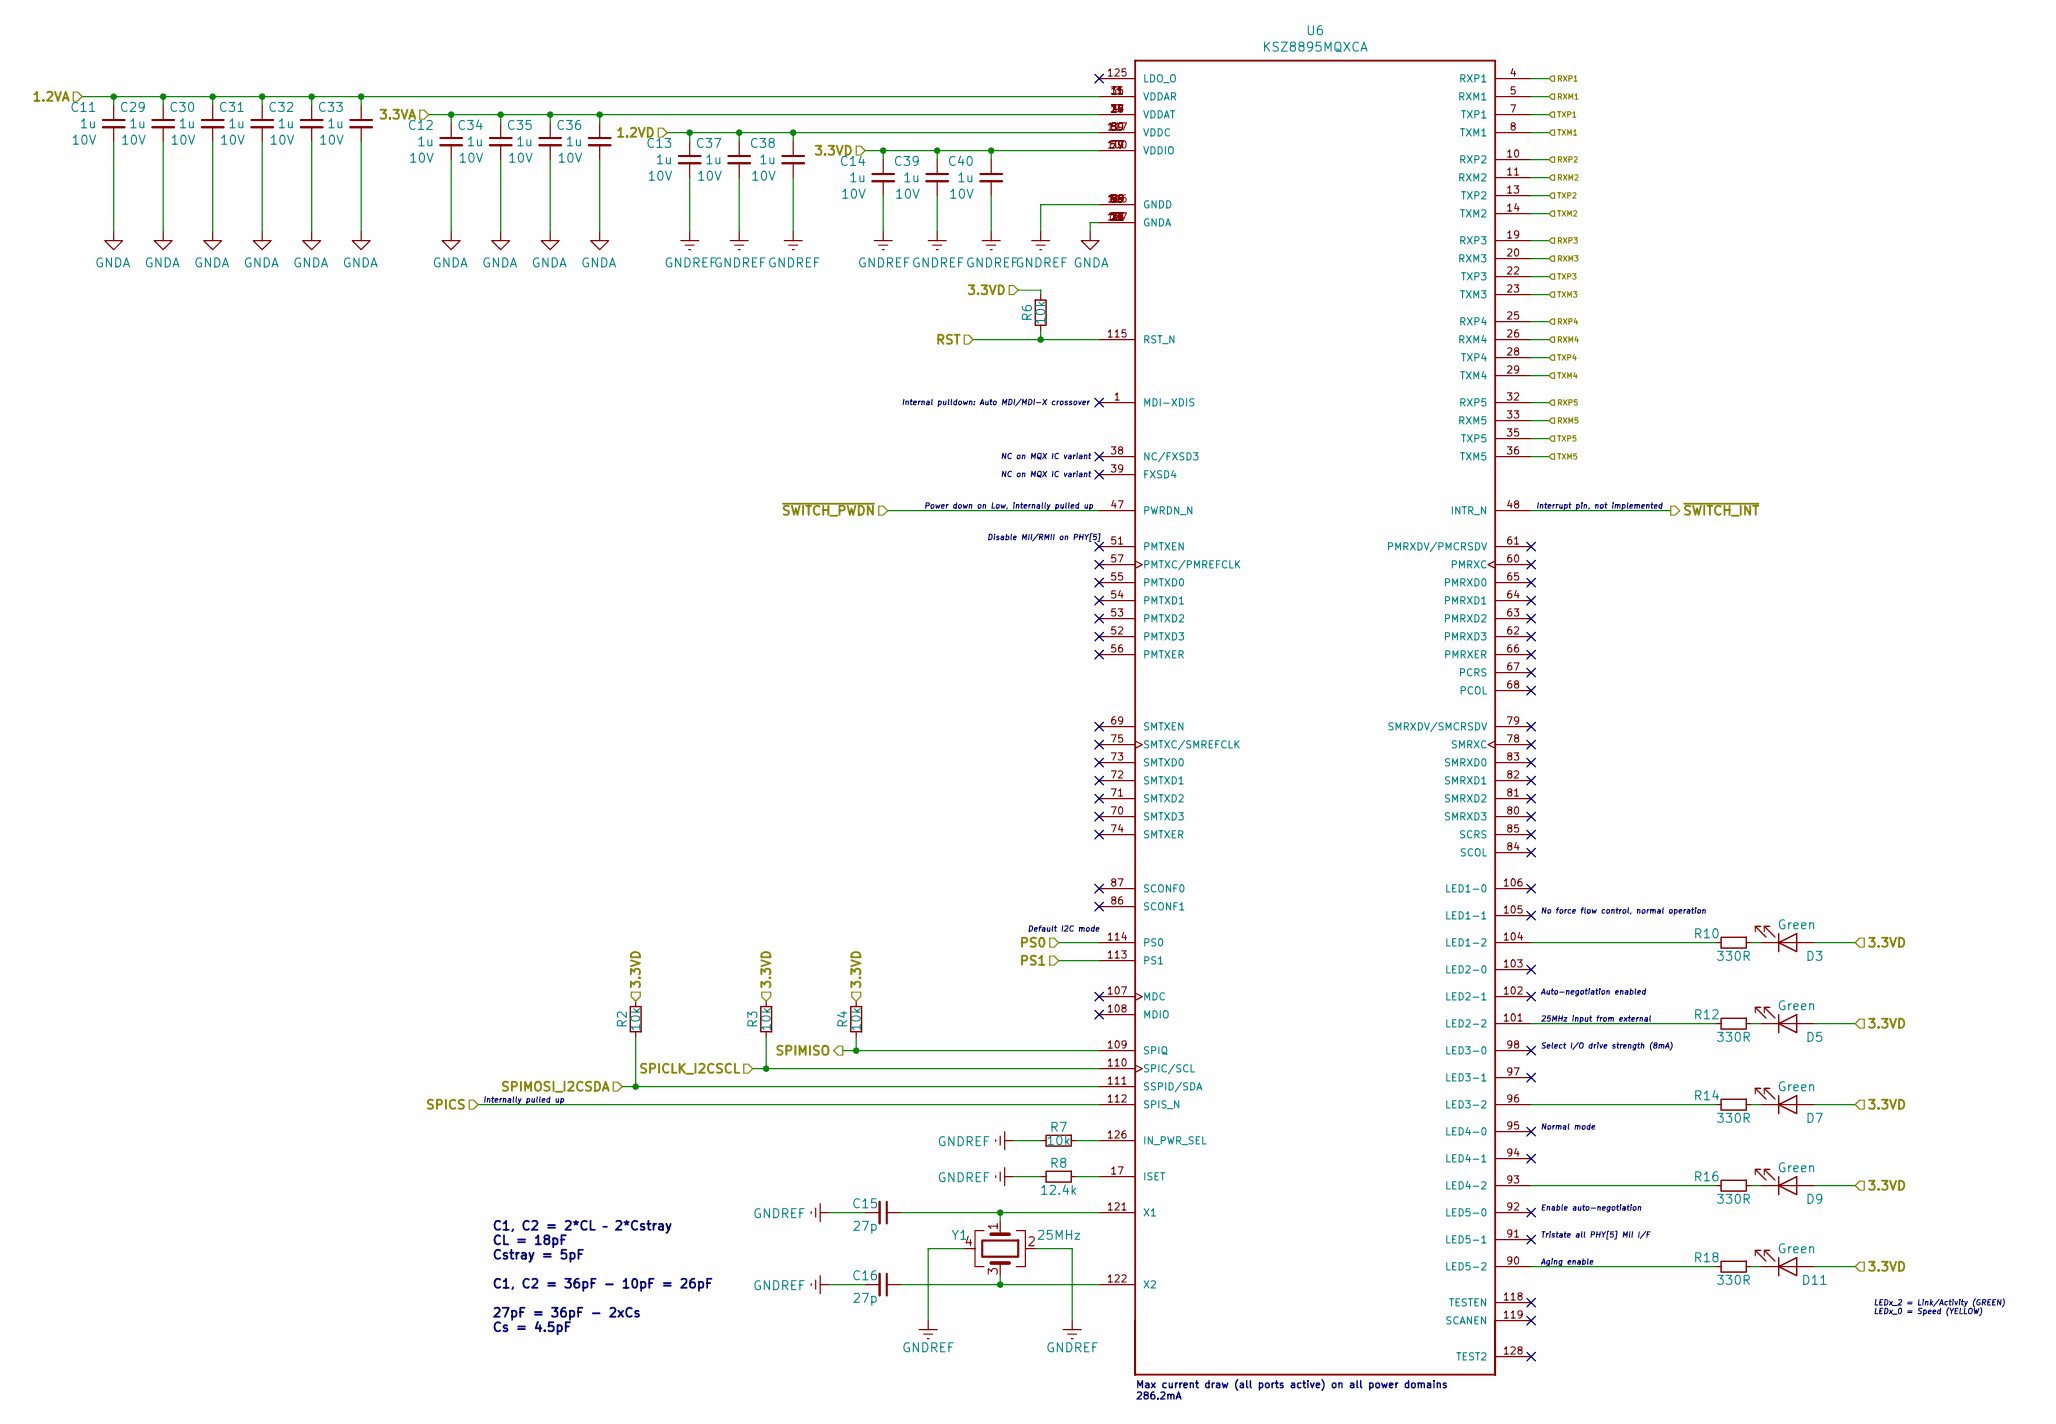
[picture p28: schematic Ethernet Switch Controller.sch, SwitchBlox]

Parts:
C11, C12, C13, C14, C29, C30, C31, C32, C33, C34, C35, C36, C37, C38, C39, C40: 1u; C_0402; Voltage Rating 10V; MPN CL05A105MP5NNNC
C15, C16: 27p; C_0402; Voltage Rating 50V; MPN CC0402JRNPO9BN270
D3, D5, D7, D9, D11: Green; LED_0603; MPN 150060GS75000
R2, R3, R4, R6, R7: 10k; R_0402; MPN RR0510P-103-D
R8: 12.4k; R_0402; Tolerance 0.5%; MPN RR0510P-1242-D
R10, R12, R14, R16, R18: 330R; R_0402; MPN CRGCQ0402F330R
U6: KSZ8895MQXCA; PQFP-128; MPN KSZ8895MQXCA
Y1: 25MHz; 4-SMD_2.50mmx2.00mm; MPN ECS-250-18-36B-CKY-TR

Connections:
3.3VD: C14.1, C39.1, C40.1, D3.2 (A), D5.2 (A), D7.2 (A), D9.2 (A), D11.2 (A), R2.2, R3.2, R4.2, R6.1, U6.59 (VDDIO), U6.77 (VDDIO), U6.100 (VDDIO); also elsewhere on the board
/Ethernet Switch Controller/1.2VA: C11.1, C29.1, C30.1, C31.1, C32.1, C33.1, U6.3 (VDDAR), U6.15 (VDDAR), U6.31 (VDDAR); also elsewhere on the board
/Ethernet Switch Controller/1.2VD: C13.1, C37.1, C38.1, U6.50 (VDDC), U6.89 (VDDC), U6.117 (VDDC); also elsewhere on the board
/Ethernet Switch Controller/3.3VA: C12.1, C34.1, C35.1, C36.1, U6.9 (VDDAT), U6.18 (VDDAT), U6.24 (VDDAT), U6.37 (VDDAT); also elsewhere on the board
/Ethernet Switch Controller/RST: R6.2, U6.115 (RST_N); also elsewhere on the board
/Ethernet Switch Controller/RXM1: U6.5 (RXM1); also elsewhere on the board
/Ethernet Switch Controller/RXM2: U6.11 (RXM2); also elsewhere on the board
/Ethernet Switch Controller/RXM3: U6.20 (RXM3); also elsewhere on the board
/Ethernet Switch Controller/RXM4: U6.26 (RXM4); also elsewhere on the board
/Ethernet Switch Controller/RXM5: U6.33 (RXM5); also elsewhere on the board
/Ethernet Switch Controller/RXP1: U6.4 (RXP1); also elsewhere on the board
/Ethernet Switch Controller/RXP2: U6.10 (RXP2); also elsewhere on the board
/Ethernet Switch Controller/RXP3: U6.19 (RXP3); also elsewhere on the board
/Ethernet Switch Controller/RXP4: U6.25 (RXP4); also elsewhere on the board
/Ethernet Switch Controller/RXP5: U6.32 (RXP5); also elsewhere on the board
/Ethernet Switch Controller/TXM1: U6.8 (TXM1); also elsewhere on the board
/Ethernet Switch Controller/TXM2: U6.14 (TXM2); also elsewhere on the board
/Ethernet Switch Controller/TXM3: U6.23 (TXM3); also elsewhere on the board
/Ethernet Switch Controller/TXM4: U6.29 (TXM4); also elsewhere on the board
/Ethernet Switch Controller/TXM5: U6.36 (TXM5); also elsewhere on the board
/Ethernet Switch Controller/TXP1: U6.7 (TXP1); also elsewhere on the board
/Ethernet Switch Controller/TXP2: U6.13 (TXP2); also elsewhere on the board
/Ethernet Switch Controller/TXP3: U6.22 (TXP3); also elsewhere on the board
/Ethernet Switch Controller/TXP4: U6.28 (TXP4); also elsewhere on the board
/Ethernet Switch Controller/TXP5: U6.35 (TXP5); also elsewhere on the board
GNDA: C11.2, C12.2, C29.2, C30.2, C31.2, C32.2, C33.2, C34.2, C35.2, C36.2, U6.2 (GNDA), U6.6 (GNDA), U6.12 (GNDA), U6.16 (GNDA), U6.21 (GNDA), U6.27 (GNDA), U6.30 (GNDA), U6.34 (GNDA), U6.127 (GNDA); also elsewhere on the board
GNDREF: C13.2, C14.2, C15.2, C16.2, C37.2, C38.2, C39.2, C40.2, R7.2, R8.2, U6.49 (GNDD), U6.58 (GNDD), U6.76 (GNDD), U6.88 (GNDD), U6.99 (GNDD), U6.116 (GNDD), Y1.2, Y1.4; also elsewhere on the board
unnamed: C15.1, U6.121 (X1), Y1.1
unnamed: C16.1, U6.122 (X2), Y1.3
unnamed: D3.1 (K), R10.1
unnamed: D5.1 (K), R12.1
unnamed: D7.1 (K), R14.1
unnamed: D9.1 (K), R16.1
unnamed: D11.1 (K), R18.1
unnamed: R7.1, U6.126 (IN_PWR_SEL)
unnamed: R8.1, U6.17 (ISET)
unnamed: R10.2, U6.104 (LED1-2)
unnamed: R12.2, U6.101 (LED2-2)
unnamed: R14.2, U6.96 (LED3-2)
unnamed: R16.2, U6.93 (LED4-2)
unnamed: R18.2, U6.90 (LED5-2)
PS0: U6.114 (PS0); also elsewhere on the board
PS1: U6.113 (PS1); also elsewhere on the board
SPICLK_I2CSCL: R3.1, U6.110 (SPIC/SCL); also elsewhere on the board
SPICS: U6.112 (SPIS_N); also elsewhere on the board
SPIMISO: R4.1, U6.109 (SPIQ); also elsewhere on the board
SPIMOSI_I2CSDA: R2.1, U6.111 (SSPID/SDA); also elsewhere on the board
~SWITCH_INT: U6.48 (INTR_N); also elsewhere on the board
~SWITCH_PWDN: U6.47 (PWRDN_N); also elsewhere on the board

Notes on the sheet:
Internal pulldown: Auto MDI/MDI-X crossover
NC on MQX IC variant
Power down on Low, internally pulled up
Interrupt pin, not implemented
Disable MII/RMII on PHY[5]
Aging enable
Tristate all PHY[5] MII I/F
Enable auto-negotiation
LEDx_2 = Link/Activity (GREEN) LEDx_0 = Speed (YELLOW)
Normal mode
Select I/O drive strength (8mA)
25MHz input from external
Auto-negotiation enabled
No force flow control, normal operation
Default I2C mode
Max current draw (all ports active) on all power domains 286.2mA
C1, C2 = 2*CL – 2*Cstray CL = 18pF Cstray = 5pF C1, C2 = 36pF - 10pF = 26pF 27pF = 36pF - 2xCs Cs = 4.5pF
Internally pulled up

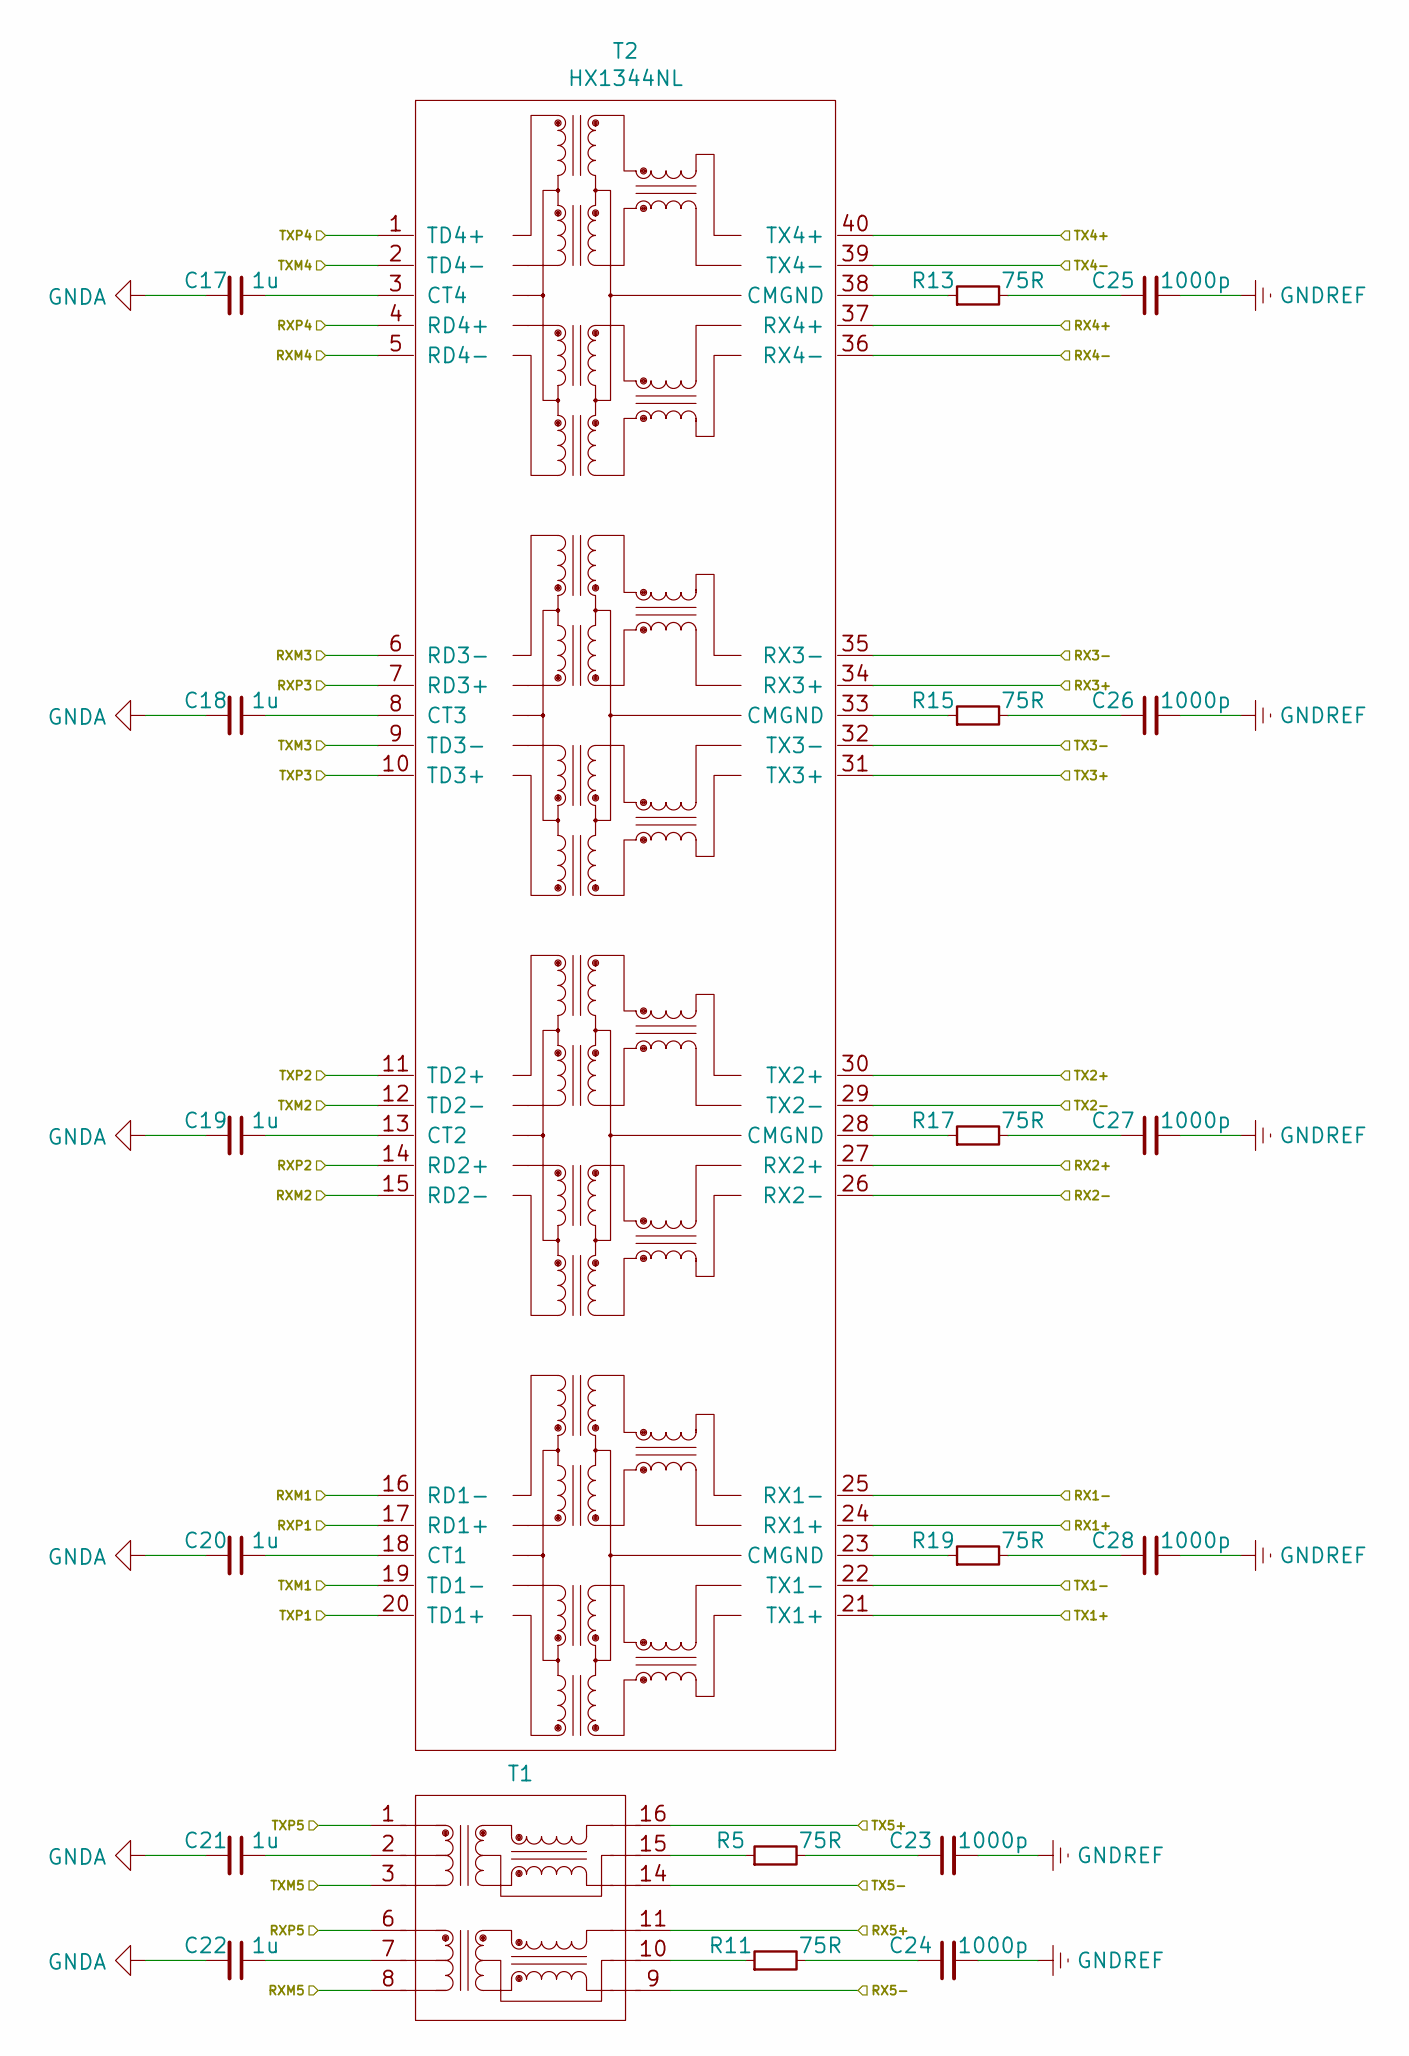
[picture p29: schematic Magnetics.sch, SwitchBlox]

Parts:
C17, C18, C19, C20, C21, C22: 1u; C_0402; Voltage Rating 10V; MPN CL05A105MP5NNNC
C23, C24, C25, C26, C27, C28: 1000p; C_0402; Voltage Rating 50V; MPN GCM155R71H102KA37D
R5, R11, R13, R15, R17, R19: 75R; R_0402; MPN ERJ-2RKF75R0X
T1: PT61017PEL; H1102FNL; MPN PT61017PEL
T2: HX1344NL; H1164NL; MPN HX1344NL

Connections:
/Ethernet Switch Controller/RXM1: T2.16 (RD1-); also elsewhere on the board
/Ethernet Switch Controller/RXM2: T2.15 (RD2-); also elsewhere on the board
/Ethernet Switch Controller/RXM3: T2.6 (RD3-); also elsewhere on the board
/Ethernet Switch Controller/RXM4: T2.5 (RD4-); also elsewhere on the board
/Ethernet Switch Controller/RXM5: T1.8; also elsewhere on the board
/Ethernet Switch Controller/RXP1: T2.17 (RD1+); also elsewhere on the board
/Ethernet Switch Controller/RXP2: T2.14 (RD2+); also elsewhere on the board
/Ethernet Switch Controller/RXP3: T2.7 (RD3+); also elsewhere on the board
/Ethernet Switch Controller/RXP4: T2.4 (RD4+); also elsewhere on the board
/Ethernet Switch Controller/RXP5: T1.6; also elsewhere on the board
/Ethernet Switch Controller/TXM1: T2.19 (TD1-); also elsewhere on the board
/Ethernet Switch Controller/TXM2: T2.12 (TD2-); also elsewhere on the board
/Ethernet Switch Controller/TXM3: T2.9 (TD3-); also elsewhere on the board
/Ethernet Switch Controller/TXM4: T2.2 (TD4-); also elsewhere on the board
/Ethernet Switch Controller/TXM5: T1.3; also elsewhere on the board
/Ethernet Switch Controller/TXP1: T2.20 (TD1+); also elsewhere on the board
/Ethernet Switch Controller/TXP2: T2.11 (TD2+); also elsewhere on the board
/Ethernet Switch Controller/TXP3: T2.10 (TD3+); also elsewhere on the board
/Ethernet Switch Controller/TXP4: T2.1 (TD4+); also elsewhere on the board
/Ethernet Switch Controller/TXP5: T1.1; also elsewhere on the board
/Magnetics/RX1+: T2.24 (RX1+); also elsewhere on the board
/Magnetics/RX1-: T2.25 (RX1-); also elsewhere on the board
/Magnetics/RX2+: T2.27 (RX2+); also elsewhere on the board
/Magnetics/RX2-: T2.26 (RX2-); also elsewhere on the board
/Magnetics/RX3+: T2.34 (RX3+); also elsewhere on the board
/Magnetics/RX3-: T2.35 (RX3-); also elsewhere on the board
/Magnetics/RX4+: T2.37 (RX4+); also elsewhere on the board
/Magnetics/RX4-: T2.36 (RX4-); also elsewhere on the board
/Magnetics/RX5+: T1.11; also elsewhere on the board
/Magnetics/RX5-: T1.9; also elsewhere on the board
/Magnetics/TX1+: T2.21 (TX1+); also elsewhere on the board
/Magnetics/TX1-: T2.22 (TX1-); also elsewhere on the board
/Magnetics/TX2+: T2.30 (TX2+); also elsewhere on the board
/Magnetics/TX2-: T2.29 (TX2-); also elsewhere on the board
/Magnetics/TX3+: T2.31 (TX3+); also elsewhere on the board
/Magnetics/TX3-: T2.32 (TX3-); also elsewhere on the board
/Magnetics/TX4+: T2.40 (TX4+); also elsewhere on the board
/Magnetics/TX4-: T2.39 (TX4-); also elsewhere on the board
/Magnetics/TX5+: T1.16; also elsewhere on the board
/Magnetics/TX5-: T1.14; also elsewhere on the board
GNDA: C17.2, C18.2, C19.2, C20.2, C21.2, C22.2; also elsewhere on the board
GNDREF: C23.2, C24.2, C25.2, C26.2, C27.2, C28.2; also elsewhere on the board
unnamed: C17.1, T2.3 (CT4)
unnamed: C18.1, T2.8 (CT3)
unnamed: C19.1, T2.13 (CT2)
unnamed: C20.1, T2.18 (CT1)
unnamed: C21.1, T1.2
unnamed: C22.1, T1.7
unnamed: C23.1, R5.2
unnamed: C24.1, R11.2
unnamed: C25.1, R13.2
unnamed: C26.1, R15.2
unnamed: C27.1, R17.2
unnamed: C28.1, R19.2
unnamed: R5.1, T1.15
unnamed: R11.1, T1.10
unnamed: R13.1, T2.38 (CMGND)
unnamed: R15.1, T2.33 (CMGND)
unnamed: R17.1, T2.28 (CMGND)
unnamed: R19.1, T2.23 (CMGND)

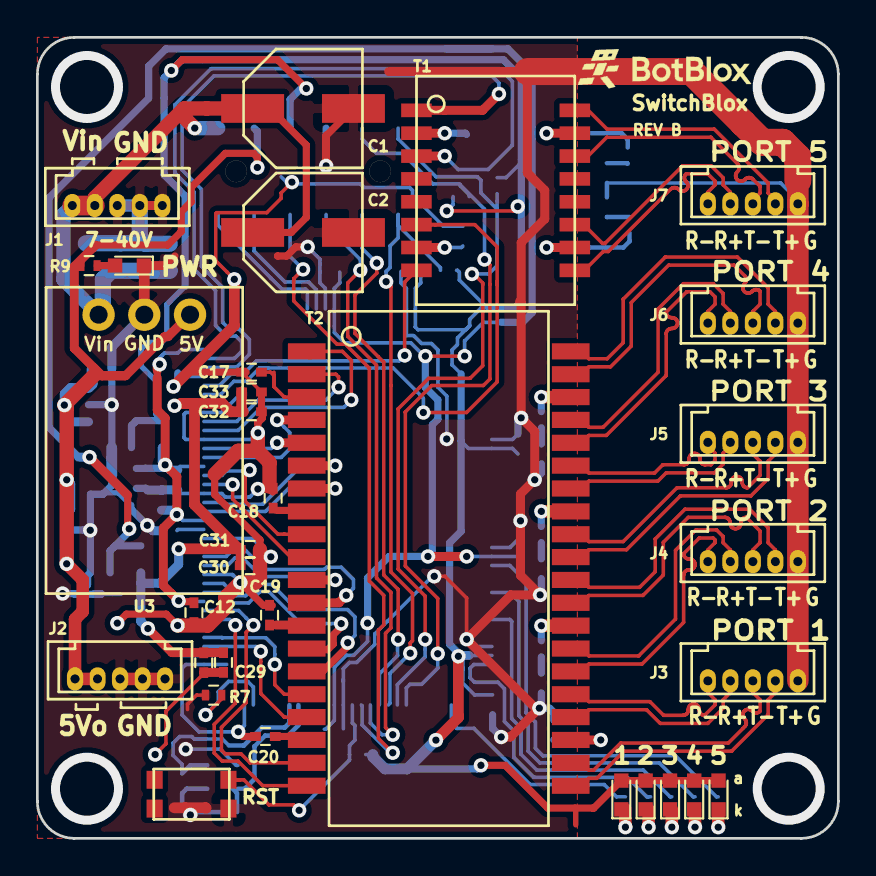
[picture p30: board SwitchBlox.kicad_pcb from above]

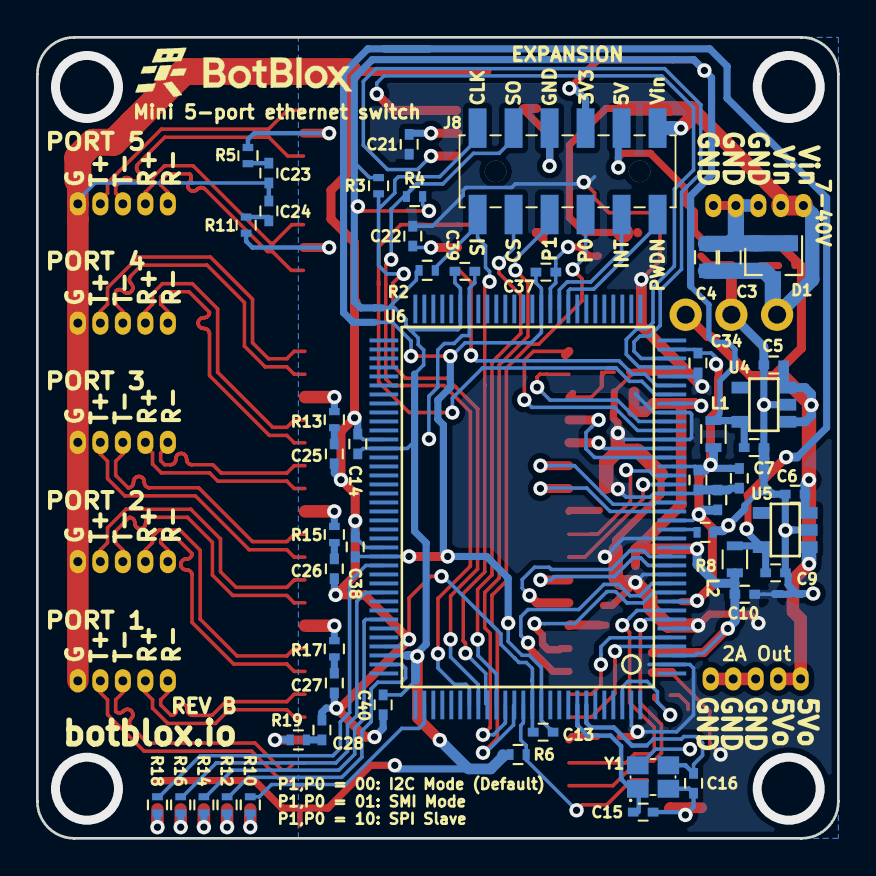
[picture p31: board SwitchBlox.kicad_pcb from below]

Board: 2 copper layers, 44.5 x 44.5 mm, 86 parts (53 on the bottom side), 90 nets.

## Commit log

2020-03-11 Added all design and manufacture files from local host
    First commit of SwitchBlox Rev B from my local host. These are the design files for the current revision B on botblox.io.
    [1042490810.stp, 45803.stp, 530470510.stp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]
2020-03-11 Restructured files, added logo.
    [1042490810.stp, 45803.stp, 530470510.stp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]
2020-03-12 Restructured files and removed old and incorrect files
    [SwitchBlox BoM.xlsx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]
